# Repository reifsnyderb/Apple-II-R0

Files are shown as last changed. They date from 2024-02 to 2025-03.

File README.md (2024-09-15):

# APPLE II R0 Reproduction #

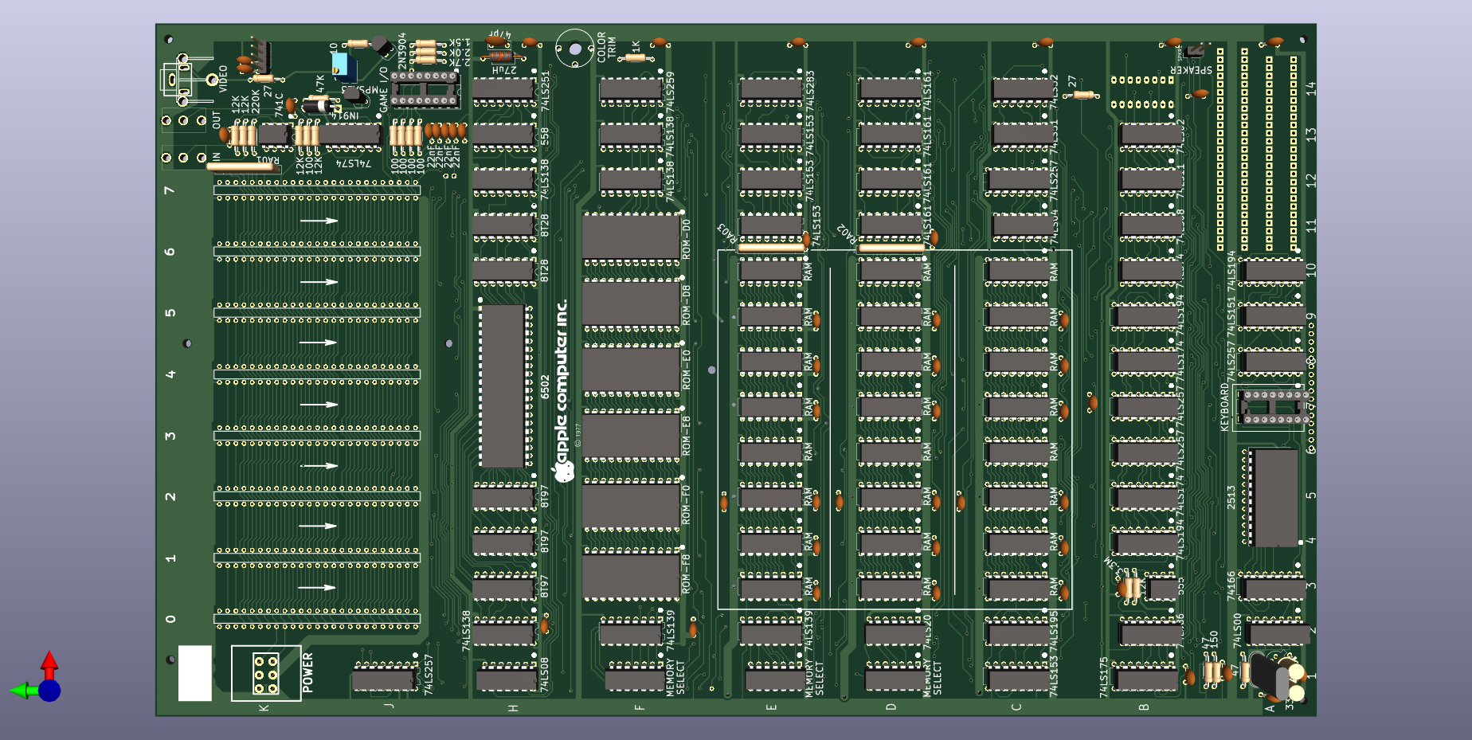
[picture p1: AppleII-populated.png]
Render of reproduction board


## Goal
The primary goal is to have an accurate KiCAD schematic of the 
Apple II Revision 0 System Board. This is supplemented with a
complete reproduction PCB that can be fabricated.

## Apple II R0 Notes

This schematic was taken from the [BitPreserve project](https://github.com/baldengineer/bit-preserve) and compared to the Apple II Gerbers by Mike Willegal (http://www.willegal.net/appleii/appleii-first_page.htm).
When necessary, The Apple II Circuit Description by Winston D. Gayler was consulted.

The PCB layout is a reworking of the Gerbers by Mike Willegal in 
KiCad. Where components are unobtainable from regular suppliers,
substitutes have been used with part number references.

## Current Status

1) Some errors have been found and corrected.
2) Minor work needs to be done to clean-up the schematic.
3) Minor cleanup is needed on the PCB.

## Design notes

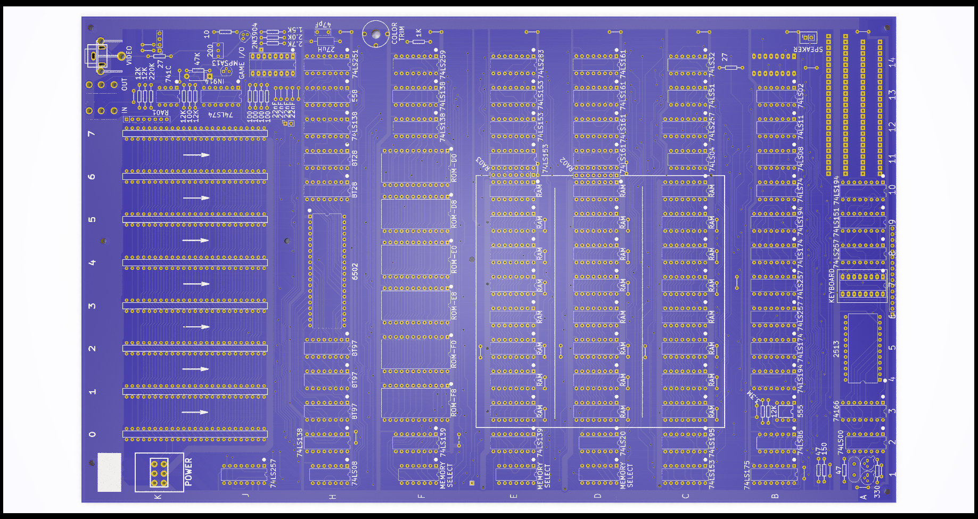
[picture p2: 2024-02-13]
AppleII.png

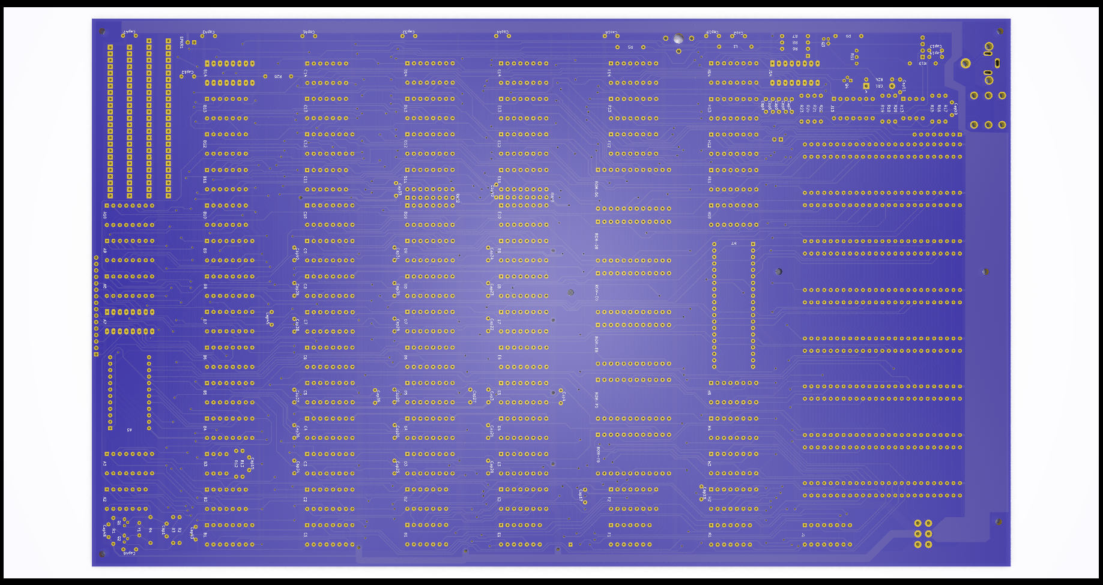
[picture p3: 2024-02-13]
AppleII-reverse.png

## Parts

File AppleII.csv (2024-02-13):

Source: | C:\Users\jimbr\Documents\KiCad\7.0\projects\Apple-II-R0\AppleII.kicad_sch
Date: | 02/02/2024 09:19:51
Tool: | Eeschema 7.0.10
Generator: | C:\Program Files\KiCad\7.0\bin\scripting\plugins/bom_csv_grouped_by_value.py
Component Count: | 196
Collated Components:
Item | Qty | Reference(s) | Value | LibPart | Footprint | Datasheet | DNP | Alt | Category | DK_Datasheet_Link | DK_Detail_Page | Description | Digi-Key_PN | DigiKey | Family | MPN | Manufacturer | Sim.Device | Sim.Pins | Status
1 | 1 | A2 | 74LS00 | 74xx:74LS00 | Package_DIP:DIP-14_W7.62mm | http://www.ti.com/lit/gpn/sn74ls00
2 | 1 | A3 | 74LS166 | 74xx:74LS166 | Package_DIP:DIP-16_W7.62mm | http://www.ti.com/lit/gpn/sn74LS166
3 | 1 | A5 | 2513 Char ROM | AppleII+:2513 | Package_DIP:DIP-24_W15.24mm
4 | 1 | A7 | Keyboard_Connector | AppleII+:AppleII+_Keyboard_Connector | Package_DIP:DIP-16_W7.62mm_Socket_LongPads
5 | 5 | A8, B6, B7, C12, J1 | 74LS257 | 74xx:74LS257 | Package_DIP:DIP-16_W7.62mm | http://www.ti.com/lit/gpn/sn74LS257
6 | 1 | A9 | 74LS151 | AppleII+:74LS151 | Package_DIP:DIP-16_W7.62mm | http://www.ti.com/lit/gpn/sn74LS151
7 | 3 | A10, B4, B9 | 74LS194 | 74xx:74LS194 | Package_DIP:DIP-16_W7.62mm | http://www.ti.com/lit/gpn/sn74LS194
8 | 1 | B1 | 74LS175 | AppleII+:74LS175 | Package_DIP:DIP-16_W7.62mm | http://www.ti.com/lit/gpn/sn74LS175
9 | 1 | B2 | 74LS86 | 74xx:74LS86 | Package_DIP:DIP-14_W7.62mm | 74xx/74ls86.pdf
10 | 1 | B3 | 555 | AppleII+:555_alt1 | Package_DIP:DIP-8_W7.62mm | http://www.ti.com/general/docs/suppproductinfo.tsp?distId=10 |  |  | Integrated Circuits (ICs) | http://www.ti.com/general/docs/suppproductinfo.tsp?distId=10 | /product-detail/en/texas-instruments/NE555P/296-1411-5-ND/277057 | IC OSC SINGLE TIMER 100KHZ 8-DIP | 296-1411-5-ND |  | Clock/Timing - Programmable Timers and Oscillators | NE555P | Texas Instruments |  |  | Active
11 | 2 | B5, B8 | 74LS174 | 74xx:74LS174 | Package_DIP:DIP-16_W7.62mm | http://www.ti.com/lit/gpn/sn74LS174
12 | 2 | B10, J13 | 74LS74 | 74xx:74LS74 | Package_DIP:DIP-14_W7.62mm | 74xx/74hc_hct74.pdf
13 | 2 | B11, H1 | 74LS08 | 74xx:74LS08 | Package_DIP:DIP-14_W7.62mm | http://www.ti.com/lit/gpn/sn74LS08
14 | 1 | B12 | 74LS11 | 74xx:74LS11 | Package_DIP:DIP-14_W7.62mm | http://www.ti.com/lit/gpn/sn74LS11
15 | 1 | B13 | 74LS02 | 74xx:74LS02 | Package_DIP:DIP-14_W7.62mm | http://www.ti.com/lit/gpn/sn74ls02
16 | 4 | C1, E11, E12, E13 | 74LS153 | 74xx:74LS153 | Package_DIP:DIP-16_W7.62mm | http://www.ti.com/lit/gpn/sn74LS153
17 | 1 | C2 | 74LS195 | 74xx:74LS195 | Package_DIP:DIP-16_W7.62mm | http://www.ti.com/lit/gpn/sn74LS195
18 | 24 | C3, C4, C5, C6, C7, C8, C9, C10, D3, D4, D5, D6, D7, D8, D9, D10, E3, E4, E5, E6, E7, E8, E9, E10 | 4116 | AppleII+:4116 | Package_DIP:DIP-16_W7.62mm
19 | 1 | C11 | 74LS04 | 74xx:74LS04 | Package_DIP:DIP-14_W7.62mm | http://www.ti.com/lit/gpn/sn74LS04
20 | 1 | C13 | 74LS51 | 74xx:74LS51 | Package_DIP:DIP-14_W7.62mm | http://www.ti.com/lit/ds/symlink/sn74ls51.pdf
21 | 1 | C14 | 74LS32 | 74xx:74LS32 | Package_DIP:DIP-14_W7.62mm | http://www.ti.com/lit/gpn/sn74LS32
22 | 37 | Cap1, Cap3, Cap4, Cap16, Cap17, Cap18, Cap19, Cap20, Cap21, Cap22, Cap23, Cap24, Cap25, Cap26, Cap27, Cap28, Cap29, Cap30, Cap31, Cap32, Cap33, Cap34, Cap35, Cap36, Cap37, Cap38, Cap39, Cap40, Cap41, Cap42, Cap43, Cap44, Cap45, Cap46, Cap47, Cap48, Cap49 | 0.1uF | Device:C_Small | Apple-II:C_Disc_D5.0mm_W2.5mm_P5.00mm | ~
23 | 1 | Cap2 | 47pf | Device:C_Small | Capacitor_THT:C_Disc_D7.0mm_W2.5mm_P5.00mm | ~
24 | 4 | Cap5, Cap6, Cap7, Cap8 | .022uF | Device:C_Small | Apple-II:C_Disc_D5.0mm_W2.5mm_P5.00mm | ~
25 | 4 | Cap9, Cap10, Cap11, Cap12 | .1uF | Device:C_Small | Apple-II:C_Disc_D5.0mm_W2.5mm_P5.00mm | ~
26 | 3 | Cap13, Cap14, Cap15 | 0.1uf | Device:C_Small | Apple-II:C_Disc_D5.0mm_W2.5mm_P5.00mm | ~
27 | 1 | CP0 | Power Connector | Connector_Generic:Conn_02x03_Odd_Even | Apple-II:POWER | https://www.te.com/commerce/DocumentDelivery/DDEController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 |  |  |  |  |  |  |  | A14226-ND
28 | 1 | CR1 | 1N914 | Device:D | Diode_THT:D_DO-15_P10.16mm_Horizontal | ~ |  |  |  |  |  |  |  |  |  |  |  | D | 1=K 2=A
29 | 1 | CT3 | 5-50pF | Device:C_Trim_Differential | Apple-II:COLOUR_TRIM | https://www.vishay.com/docs/28528/bfc2808-10mm.pdf |  |  |  |  |  |  |  | BFC280831659-ND
30 | 3 | D1, E1, F1 | Memory Type Sel | AppleII+:AppII_MemorySelectBlock | Package_DIP:DIP-14_W7.62mm
31 | 1 | D2 | 74LS20 | 74xx:74LS20 | Package_DIP:DIP-14_W7.62mm | http://www.ti.com/lit/gpn/sn74LS20
32 | 4 | D11, D12, D13, D14 | 74LS161 | AppleII+:74LS161 | Package_DIP:DIP-16_W7.62mm | http://www.ti.com/lit/gpn/sn74LS161
33 | 2 | E2, F2 | 74LS139 | 74xx:74LS139 | Package_DIP:DIP-16_W7.62mm | http://www.ti.com/lit/ds/symlink/sn74ls139a.pdf
34 | 1 | E14 | 74LS283 | 74xx:74LS283 | Package_DIP:DIP-16_W7.62mm | http://www.ti.com/lit/gpn/sn74LS283
35 | 4 | F12, F13, H2, H12 | 74LS138 | 74xx:74LS138 | Package_DIP:DIP-16_W7.62mm | http://www.ti.com/lit/gpn/sn74LS138
36 | 1 | F14 | 74LS259 | 74xx:74LS259 | Package_DIP:DIP-16_W7.62mm | http://www.ti.com/lit/gpn/sn74LS259
37 | 2 | H3, H4 | 8T97 | AppleII+:8T97 | Package_DIP:DIP-16_W7.62mm
38 | 1 | H5 | 8T97 | AppleII-rescue:8T97-AppleII | Package_DIP:DIP-16_W7.62mm
39 | 1 | H7 | 6502 | AppleII-rescue:MOS6502-AppleII | Package_DIP:DIP-40_W15.24mm
40 | 2 | H10, H11 | 8T28 | AppleII-rescue:8T28-AppleII | Package_DIP:DIP-16_W7.62mm
41 | 1 | H13 | NE558 | AppleII+:NE558 | Package_DIP:DIP-16_W7.62mm
42 | 1 | H14 | 74LS251 | 74xx:74LS251 | Package_DIP:DIP-16_W7.62mm | http://www.ti.com/lit/gpn/sn74LS251
43 | 1 | J0 | Cassette Data In | Connector_Audio:AudioJack2_Ground | Apple-II:AUDIO_mono | https://www.cuidevices.com/product/resource/mj-3502n.pdf |  |  |  |  |  |  |  | CP-3502N-ND
44 | 1 | J2 | Cassette Data Out | Connector_Audio:AudioJack2_Ground | Apple-II:AUDIO_mono | https://www.cuidevices.com/product/resource/mj-3502n.pdf |  |  |  |  |  |  |  | CP-3502N-ND
45 | 1 | J3 | Conn_01x16 | Connector_Generic:Conn_01x16 | Connector_PinHeader_2.54mm:PinHeader_1x16_P2.54mm_Vertical | ~
46 | 1 | J14 | GAME_IO_Conn | AppleII+:GAME_IO_Conn | Package_DIP:DIP-16_W7.62mm_Socket_LongPads
47 | 1 | J18 | Aux Video | Connector_Generic:Conn_01x04 | Connector_PinHeader_2.54mm:PinHeader_1x04_P2.54mm_Vertical | ~
48 | 1 | JP-User1 | Jumper | Jumper:Jumper_2_Open | Connector_PinSocket_2.54mm:PinSocket_1x02_P2.54mm_Vertical | ~ | DNP
49 | 1 | K13 | MA741 | Amplifier_Operational:LM741 | Package_DIP:DIP-8_W7.62mm | http://www.ti.com/lit/ds/symlink/lm741.pdf
50 | 1 | K14 | RCA Connector | Apple-II:Video | Apple-II:VIDEO | https://www.switchcraft.com/assets/1/24/pjran1x1u__x_series_cd.pdf?4664 |  |  |  |  |  |  |  | PJRAN1X1U03X-ND
51 | 1 | L1 | 27uH | Device:L | Inductor_THT:L_Axial_L7.0mm_D3.3mm_P12.70mm_Horizontal_Fastron_MICC | ~
52 | 7 | MH1, MH2, MH3, MH4, MH5, MH6, MH7 | MountingHole | Mechanical:MountingHole | MountingHole:MountingHole_2.5mm | ~
53 | 2 | Q1, Q2 | 2N4258 | Device:Q_PNP_EBC | Package_TO_SOT_THT:TO-18-3 | ~ |  | 2N4208 |  |  |  |  |  | 2N4208-ND
54 | 1 | Q3 | 2N3904 | AppleII-rescue:2N3904-dk_Transistors-Bipolar-BJT-Single | Package_TO_SOT_THT:TO-92 | https://my.centralsemi.com/get_document.php?cmp=1&mergetype=pd&mergepath=pd&pdf_id=LSSGP072.PDF |  |  | Discrete Semiconductor Products | https://my.centralsemi.com/get_document.php?cmp=1&mergetype=pd&mergepath=pd&pdf_id=LSSGP072.PDF | /product-detail/en/central-semiconductor-corp/2N3904/2N3904CS-ND/4806876 | TRANS NPN 40V TO-92 | 2N3904CS-ND |  | Transistors - Bipolar (BJT) - Single | 2N3904 | Central Semiconductor Corp |  |  | Active
55 | 1 | Q4 | MPSA13 | Device:Q_NPN_Darlington_EBC | Package_TO_SOT_THT:TO-92 | ~ |  | KSP13 |  |  |  |  |  | KSP13BU-ND
56 | 1 | R1 | 330R | Device:R | Apple-II:R_Axial_DIN0207_L6.3mm_D2.5mm_P10.16mm_Horizontal | ~
57 | 2 | R2, R4 | 47R | Device:R | Apple-II:R_Axial_DIN0207_L6.3mm_D2.5mm_P10.16mm_Horizontal | ~
58 | 1 | R3 | 150R | Device:R | Apple-II:R_Axial_DIN0207_L6.3mm_D2.5mm_P10.16mm_Horizontal | ~
59 | 1 | R5 | 1K | Device:R | Apple-II:R_Axial_DIN0207_L6.3mm_D2.5mm_P10.16mm_Horizontal | ~
60 | 1 | R6 | 2K7 | Device:R | Apple-II:R_Axial_DIN0207_L6.3mm_D2.5mm_P10.16mm_Horizontal | ~
61 | 1 | R7 | 1K5 | Device:R | Apple-II:R_Axial_DIN0207_L6.3mm_D2.5mm_P10.16mm_Horizontal | ~
62 | 1 | R8 | 2K | Device:R | Apple-II:R_Axial_DIN0207_L6.3mm_D2.5mm_P10.16mm_Horizontal | ~
63 | 1 | R9 | 10R | Device:R | Apple-II:R_Axial_DIN0207_L6.3mm_D2.5mm_P10.16mm_Horizontal | ~
64 | 1 | R10 | 27R | Device:R | Apple-II:R_Axial_DIN0207_L6.3mm_D2.5mm_P10.16mm_Horizontal | ~
65 | 1 | R11 | 200R | AppleII-rescue:R_POT_TRIM_US-Device | Potentiometer_THT:Potentiometer_Bourns_3266Y_Vertical
66 | 1 | R12 | 12K | Device:R | Apple-II:R_Axial_DIN0207_L6.3mm_D2.5mm_P10.16mm_Horizontal | ~
67 | 1 | R13 | 3M3 | Device:R | Apple-II:R_Axial_DIN0207_L6.3mm_D2.5mm_P10.16mm_Horizontal | ~
68 | 1 | R15 | 220k | Device:R_Small | Apple-II:R_Axial_DIN0207_L6.3mm_D2.5mm_P10.16mm_Horizontal | ~
69 | 4 | R16, R17, R19, R29 | 12K | Device:R_Small | Apple-II:R_Axial_DIN0207_L6.3mm_D2.5mm_P10.16mm_Horizontal | ~
70 | 5 | R18, R20, R21, R22, R23 | 100R | Device:R_Small | Apple-II:R_Axial_DIN0207_L6.3mm_D2.5mm_P10.16mm_Horizontal | ~
71 | 1 | R24 | 47K | Device:R_Small | Apple-II:R_Axial_DIN0207_L6.3mm_D2.5mm_P10.16mm_Horizontal | ~
72 | 1 | R25 | 27R | Device:R_Small | Apple-II:R_Axial_DIN0207_L6.3mm_D2.5mm_P10.16mm_Horizontal | ~
73 | 1 | RA01 | 1k | Device:R_Network07_US | Resistor_THT:R_Array_SIP8 | http://www.vishay.com/docs/31509/csc.pdf
74 | 2 | RA02, RA03 | 1K | Device:R_Network07_US | Resistor_THT:R_Array_SIP8 | http://www.vishay.com/docs/31509/csc.pdf
75 | 6 | ROM-D0, ROM-D8, ROM-E0, ROM-E8, ROM-F0, ROM-F8 | ROM_Chip | AppleII+:ROM_Chip | Package_DIP:DIP-24_W15.24mm
76 | 8 | SLOT0, SLOT1, SLOT2, SLOT3, SLOT4, SLOT5, SLOT6, SLOT7 | 50 pin slot | Connector_Generic:Conn_02x25_Counter_Clockwise | Apple-II:Standard_Edge_Connector | ~ |  |  |  |  |  |  |  | A31718-ND
77 | 1 | SPKR1 | Speaker Connector | AppleII-rescue:22-23-2021-dk_Rectangular-Connectors-Headers-Male-Pins | Connector_PinSocket_2.54mm:PinSocket_1x02_P2.54mm_Vertical | https://media.digikey.com/pdf/Data%20Sheets/Molex%20PDFs/A-6373-N_Series_Dwg_2010-12-03.pdf |  |  | Connectors, Interconnects | https://media.digikey.com/pdf/Data%20Sheets/Molex%20PDFs/A-6373-N_Series_Dwg_2010-12-03.pdf | /product-detail/en/molex/22-23-2021/WM4200-ND/26667 | CONN HEADER VERT 2POS 2.54MM | WM4200-ND |  | Rectangular Connectors - Headers, Male Pins | 22-23-2021 | Molex |  |  | Active
78 | 1 | Y1 | XT0001 | Device:Crystal | Crystal:Crystal_HC18-U_Vertical | ~

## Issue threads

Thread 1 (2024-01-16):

PC Board file is needed

reifsnyderb, 2024-01-16:
PC Board file is missing as it was made from imported gerber files from M. Willegal's Apple II Revision 0 board.  KiCad, unfortunately, imported them with the wrong track thickness.  Extensive work will be required to re-set the track thicknesses properly.

jimbro1000, 2024-01-27:
I've started routing tracks by hand based on those gerbers and found some issues with the schematics as a result - will post them as separate issues

reifsnyderb, 2024-02-13:
PCB board is now available.  Closing issue.

Closed 2024-02-13.

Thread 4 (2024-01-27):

Incorrect use of labels

jimbro1000, 2024-01-27:
On the Connectors sheet (page 7) you've used local labels to match against global labels but on the CPU sheet (page 2) you've matched local labels against hierarchical labels. The result is that on a PCB these do not actually connect.

This impacts NMI, IRQ, RDY and RESET

reifsnyderb, 2024-01-27:
NMI, IRQ, and RDY are fixed.  RESET still appears to have some issue.

jimbro1000, 2024-01-29:
This happens again (sort of) with the ROM_Select_Dn lines. You've used local labels for them but they are distributed over page 9 and 5 so the connection is not made on the PCB

reifsnyderb, 2024-01-30:
ROM Select Line issue fixed.

reifsnyderb, 2024-01-30:
RESET fixed.

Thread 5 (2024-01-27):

Slot 0-7 connection pin 19

jimbro1000, 2024-01-27:
Based on the imported gerbers, pin 19 of the 8 slots are cross-wired together but are otherwise unused

reifsnyderb, 2024-01-28:
Fixed connections with pins 19 and pins 35.

Closed 2024-01-28.

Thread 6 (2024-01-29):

Label mismatch on IO-Select-N

jimbro1000, 2024-01-29:
The global labels for IO Select are mismatched
On page 7 they are fully uppercase (eg IO-SELECT-6) but on 9 they are mixed case (eg IO-Select-6)
The labels are case-sensitive and do not match up

reifsnyderb, 2024-01-30:
Fixed.

Closed 2024-01-30.

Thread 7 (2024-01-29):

Unit H1E (VCC and GND) is missing

jimbro1000, 2024-01-29:
The final unit for H1 is missing from the schematic

reifsnyderb, 2024-01-30:
Added.

Closed 2024-01-30.

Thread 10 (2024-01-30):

More SOFT5 connections

jimbro1000, 2024-01-30:
B10 pin 10 is shown as unconnected but is wired to SOFT5 on the PCB (note pin 12 is also unconnected correctly but not tagged as such)

reifsnyderb, 2024-01-30:
Fixed.

Closed 2024-01-30.

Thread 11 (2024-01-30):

D2 unit C missing

jimbro1000, 2024-01-30:
D2 unit C is missing from the schematic

reifsnyderb, 2024-01-30:
Fixed.

Closed 2024-01-30.

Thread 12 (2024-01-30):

Crosswired connection on D12

jimbro1000, 2024-01-30:
!PE is cross wired with D0-D3, CET and CEP. On the PCB !PE is not connected. D11 doesn't have the cross wired connection

reifsnyderb, 2024-01-31:
Fixed.

Closed 2024-01-31.

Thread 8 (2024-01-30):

H14 - Pin 6 incorrect

jimbro1000, 2024-01-30:
This is tied to ground on the PCB

reifsnyderb, 2024-01-30:
This issue is rather somewhat conflicting.  The PCB clearly ties this to ground.  However, H14 pin 6 of the 74LS251 is an output and would be shorted out to ground when it is high.  Maybe this is a PCB error?

reifsnyderb, 2024-01-30:
A note has been put on the schematic as a temporary measure.

reifsnyderb, 2024-02-01:
Attempting to contact Mike Willegal to determine if this was an error on the Apple II Rev 0 boards.

reifsnyderb, 2024-02-02:
This has been confirmed, by Mike Willegal, to be a mistake and will be corrected on the PCB.

reifsnyderb, 2024-02-02:
PCB has been fixed.

Closed 2024-02-02.

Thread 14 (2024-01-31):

!MR on D11 and D12

jimbro1000, 2024-01-31:
PCB shows !MR for D11 and D12 connected to SOFT5 - schematic shows the two ICs connected but not to anything else which is unlikely to be correct

reifsnyderb, 2024-01-31:
Fixed

Closed 2024-01-31.

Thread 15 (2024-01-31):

C13 unit C and C14 unit E missing

jimbro1000, 2024-01-31:
C13C and C14E are missing from the schematic

jimbro1000, 2024-01-31:
Need to add C11G to the list

jimbro1000, 2024-01-31:
And B2E

jimbro1000, 2024-01-31:
And B13E

Closed 2024-01-31.

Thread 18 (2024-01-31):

A2 Unit E missing

jimbro1000, 2024-01-31:
Unit E of IC A2 is missing from the schematic

reifsnyderb, 2024-01-31:
Fixed

Closed 2024-01-31.

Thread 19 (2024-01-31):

A8 wiring mismatch

jimbro1000, 2024-01-31:
PCB shows A8 15 (!OE), 13 8 and 6 are all wired together (GND) not to another signal (labelled A8-6) as indicated on the schematic

reifsnyderb, 2024-01-31:
Fixed.

Closed 2024-01-31.

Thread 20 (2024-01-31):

Not an issue - PCB routing completed

jimbro1000, 2024-01-31:
I think I've finished routing the PCB with all of the updates and changes I've raised but this is now out of sync with your schematics so I'm not going to just raise a pull request

The cosmetics of the board still need work to get all of the labelling correct, likewise placing of mounting holes

See my fork of the repo for renders and pcb files for comparison

jimbro1000, 2024-01-31:
OK - not quite finished, there is an issue with the SOFT5 net. There are two separate nets labelled SOFT5 generated from A2 (pin 8 and pin 11). Other than the gates driving them being on the same chip, they are not otherwise connected. Given that SOFT5 is just always high (inverted GND) I suggest that the net names are changed... the only impact is fixing DRC errors on the PCB, the schematic is otherwise correct

reifsnyderb, 2024-01-31:
Make them SOFT5a and SOFT5b?  Tracking down this issue could take a while.

jimbro1000, 2024-01-31:
That's what I was thinking - it is really quick to isolate the nets in the PCB editor so I should be able to give you a list of the two sides

jimbro1000, 2024-01-31:
I've found modern substitutes for everything except the character rom but it should be simple enough to convert a 27C16 to suit

reifsnyderb, 2024-01-31:
Thank you for all your work on this!  I just downloaded and was looking at your PCB.  It's looking good!

When ready (no rush), post a list and I'll isolate the two SOFT5 nets.

reifsnyderb, 2024-01-31:
I just found and opened up the discussion section.

Are these modern substitutes still being made?

jimbro1000, 2024-01-31:
Other than the roms I think everything is current on digikey and I've tagged components with the digikey part numbers as I've identified them. The roms can be directly substituted with 27c16 EPROMs but the character Rom is problematic by comparison

Closed 2024-02-02.

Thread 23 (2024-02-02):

Loose ends

jimbro1000, 2024-02-02:
There are two incomplete tracks in the original gerbers
Net-(E2A-O0) heads west near the edge of the board (just above E1) but I can't identify anything it intended to connect to

The Color_Burst trace heads west from R6 (connects R6,R7 and R8). It looks as though there was meant to be a fourth resistor in the bank but was not implemented. There is nowhere for the pads to fit as the traces from J14 occupy that space

Before I simply delete the loose ends can you verify I haven't missed anything against the old boards you have?
This is an otherwise cosmetic problem

reifsnyderb, 2024-02-02:
The Color_Burst trace goes to a via that appears it could be used as a test point. The metal around the via is masked off.  If the via size is unclear, let me know and I'll take some accurate measurements.  I also checked Mike Willegal's site and he has a close-up of this area and this trace (and via) is on the original Apple II R 0.

The E2A-O0 appears on the board as well.  It terminates as a VIA.  I found a close-up here:  https://medium.com/@piedad/prime-properties-for-sale-e398359440a  So, it appears it should be left in place.

Closed 2024-02-02.

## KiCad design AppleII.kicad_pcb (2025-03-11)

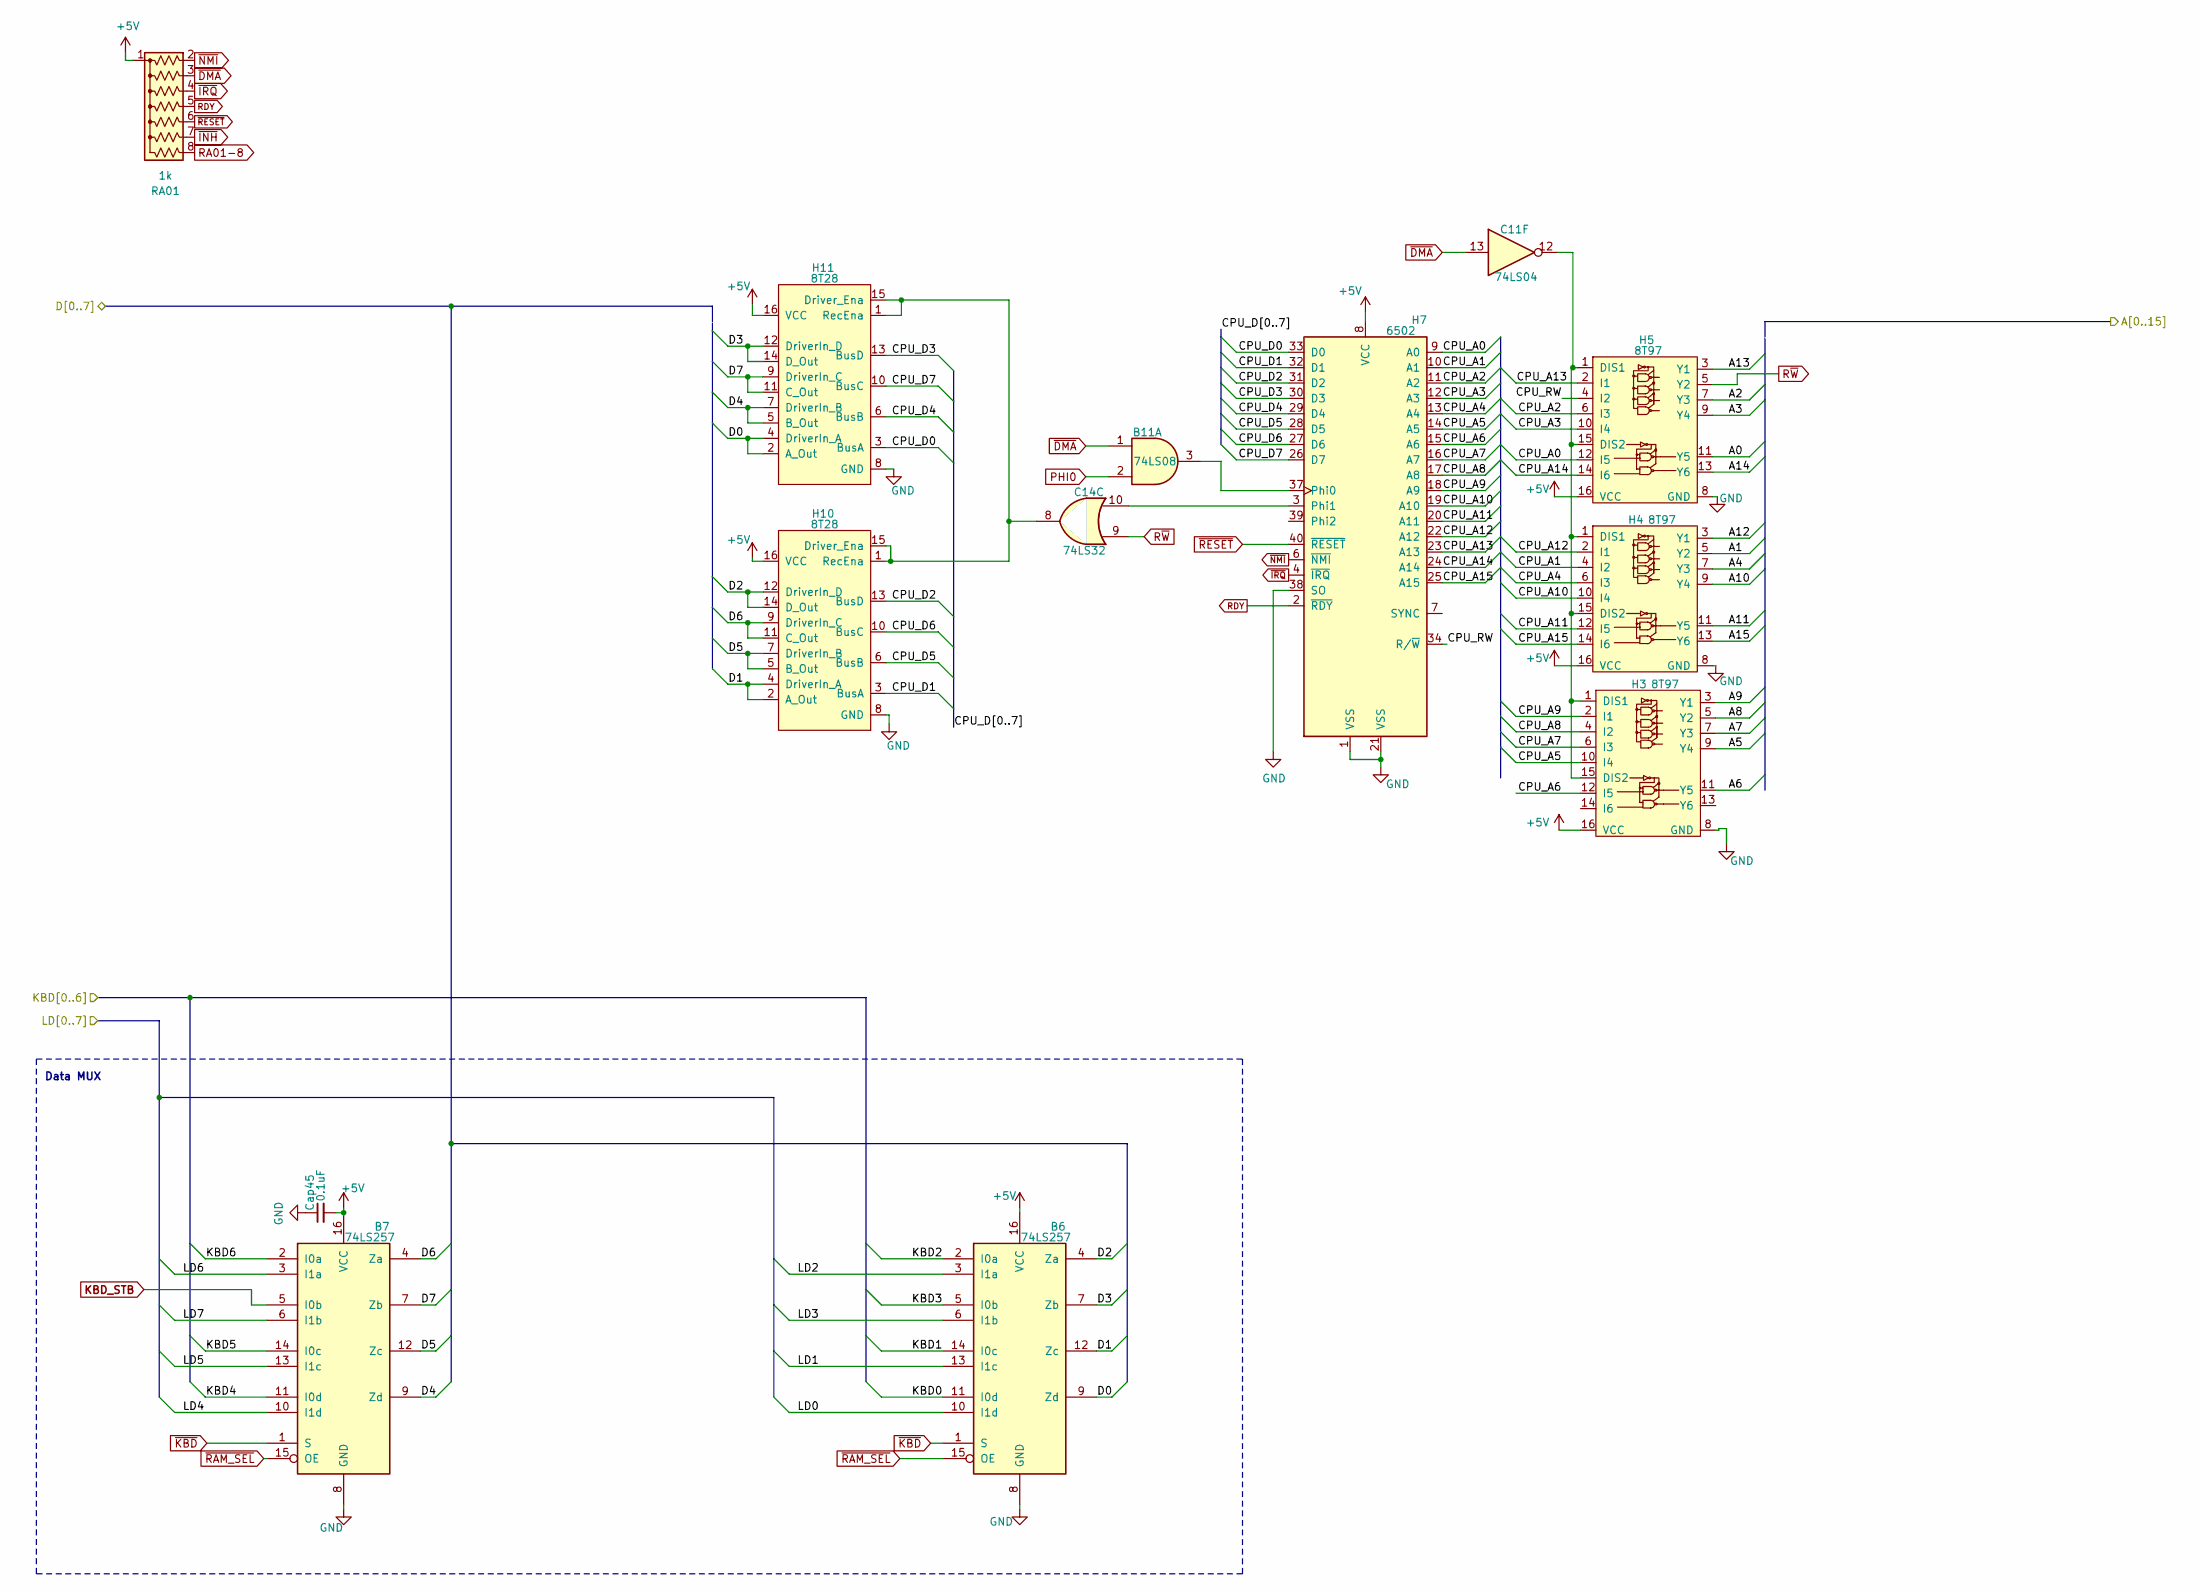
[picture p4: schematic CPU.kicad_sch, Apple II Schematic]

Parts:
B6, B7: 74LS257; DIP-16_W7.62mm
B11: 74LS08; DIP-14_W7.62mm
C11: 74LS04; DIP-14_W7.62mm
C14: 74LS32; DIP-14_W7.62mm
Cap45: 0.1uF; C_Disc_D5.0mm_W2.5mm_P5.00mm
H3, H4, H5: 8T97; DIP-16_W7.62mm
H7: 6502; DIP-40_W15.24mm
H10, H11: 8T28; DIP-16_W7.62mm
RA01: 1k; R_Array_SIP8

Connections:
+5V: B6.16 (VCC), B7.16 (VCC), Cap45.2, H3.16 (VCC), H4.16 (VCC), H5.16 (VCC), H7.8 (VCC), H10.16 (VCC), H11.16 (VCC), RA01.1 (common); also elsewhere on the board
/Address Decoder and Onboard IO/KBD0: B6.11 (I0d); also elsewhere on the board
/Address Decoder and Onboard IO/KBD1: B6.14 (I0c); also elsewhere on the board
/Address Decoder and Onboard IO/KBD2: B6.2 (I0a); also elsewhere on the board
/Address Decoder and Onboard IO/KBD3: B6.5 (I0b); also elsewhere on the board
/Address Decoder and Onboard IO/KBD4: B7.11 (I0d); also elsewhere on the board
/Address Decoder and Onboard IO/KBD5: B7.14 (I0c); also elsewhere on the board
/Address Decoder and Onboard IO/KBD6: B7.2 (I0a); also elsewhere on the board
/CPU Tranceiver Driver and Data MUX/CPU_A0: H5.12 (I5), H7.9 (A0)
/CPU Tranceiver Driver and Data MUX/CPU_A1: H4.4 (I2), H7.10 (A1)
/CPU Tranceiver Driver and Data MUX/CPU_A2: H5.6 (I3), H7.11 (A2)
/CPU Tranceiver Driver and Data MUX/CPU_A3: H5.10 (I4), H7.12 (A3)
/CPU Tranceiver Driver and Data MUX/CPU_A4: H4.6 (I3), H7.13 (A4)
/CPU Tranceiver Driver and Data MUX/CPU_A5: H3.10 (I4), H7.14 (A5)
/CPU Tranceiver Driver and Data MUX/CPU_A6: H3.12 (I5), H7.15 (A6)
/CPU Tranceiver Driver and Data MUX/CPU_A7: H3.6 (I3), H7.16 (A7)
/CPU Tranceiver Driver and Data MUX/CPU_A8: H3.4 (I2), H7.17 (A8)
/CPU Tranceiver Driver and Data MUX/CPU_A9: H3.2 (I1), H7.18 (A9)
/CPU Tranceiver Driver and Data MUX/CPU_A10: H4.10 (I4), H7.19 (A10)
/CPU Tranceiver Driver and Data MUX/CPU_A11: H4.12 (I5), H7.20 (A11)
/CPU Tranceiver Driver and Data MUX/CPU_A12: H4.2 (I1), H7.22 (A12)
/CPU Tranceiver Driver and Data MUX/CPU_A13: H5.2 (I1), H7.23 (A13)
/CPU Tranceiver Driver and Data MUX/CPU_A14: H5.14 (I6), H7.24 (A14)
/CPU Tranceiver Driver and Data MUX/CPU_A15: H4.14 (I6), H7.25 (A15)
/CPU Tranceiver Driver and Data MUX/CPU_D0: H7.33 (D0), H11.3 (BusA)
/CPU Tranceiver Driver and Data MUX/CPU_D1: H7.32 (D1), H10.3 (BusA)
/CPU Tranceiver Driver and Data MUX/CPU_D2: H7.31 (D2), H10.13 (BusD)
/CPU Tranceiver Driver and Data MUX/CPU_D3: H7.30 (D3), H11.13 (BusD)
/CPU Tranceiver Driver and Data MUX/CPU_D4: H7.29 (D4), H11.6 (BusB)
/CPU Tranceiver Driver and Data MUX/CPU_D5: H7.28 (D5), H10.6 (BusB)
/CPU Tranceiver Driver and Data MUX/CPU_D6: H7.27 (D6), H10.10 (BusC)
/CPU Tranceiver Driver and Data MUX/CPU_D7: H7.26 (D7), H11.10 (BusC)
/CPU Tranceiver Driver and Data MUX/CPU_RW: H5.4 (I2), H7.34 (R/~W)
/CPU Tranceiver Driver and Data MUX/LD0: B6.10 (I1d); also elsewhere on the board
/CPU Tranceiver Driver and Data MUX/LD1: B6.13 (I1c); also elsewhere on the board
/CPU Tranceiver Driver and Data MUX/LD2: B6.3 (I1a); also elsewhere on the board
/CPU Tranceiver Driver and Data MUX/LD3: B6.6 (I1b); also elsewhere on the board
/CPU Tranceiver Driver and Data MUX/LD4: B7.10 (I1d); also elsewhere on the board
/CPU Tranceiver Driver and Data MUX/LD5: B7.13 (I1c); also elsewhere on the board
/CPU Tranceiver Driver and Data MUX/LD6: B7.3 (I1a); also elsewhere on the board
/CPU Tranceiver Driver and Data MUX/LD7: B7.6 (I1b); also elsewhere on the board
A0: H5.11 (Y5); also elsewhere on the board
A1: H4.5 (Y2); also elsewhere on the board
A2: H5.7 (Y3); also elsewhere on the board
A3: H5.9 (Y4); also elsewhere on the board
A4: H4.7 (Y3); also elsewhere on the board
A5: H3.9 (Y4); also elsewhere on the board
A6: H3.11 (Y5); also elsewhere on the board
A7: H3.7 (Y3); also elsewhere on the board
A8: H3.5 (Y2); also elsewhere on the board
A9: H3.3 (Y1); also elsewhere on the board
A10: H4.9 (Y4); also elsewhere on the board
A11: H4.11 (Y5); also elsewhere on the board
A12: H4.3 (Y1); also elsewhere on the board
A13: H5.3 (Y1); also elsewhere on the board
A14: H5.13 (Y6); also elsewhere on the board
A15: H4.13 (Y6); also elsewhere on the board
D0: B6.9 (Zd), H11.2 (A_Out), H11.4 (DriverIn_A); also elsewhere on the board
D1: B6.12 (Zc), H10.2 (A_Out), H10.4 (DriverIn_A); also elsewhere on the board
D2: B6.4 (Za), H10.12 (DriverIn_D), H10.14 (D_Out); also elsewhere on the board
D3: B6.7 (Zb), H11.12 (DriverIn_D), H11.14 (D_Out); also elsewhere on the board
D4: B7.9 (Zd), H11.5 (B_Out), H11.7 (DriverIn_B); also elsewhere on the board
D5: B7.12 (Zc), H10.5 (B_Out), H10.7 (DriverIn_B); also elsewhere on the board
D6: B7.4 (Za), H10.9 (DriverIn_C), H10.11 (C_Out); also elsewhere on the board
D7: B7.7 (Zb), H11.9 (DriverIn_C), H11.11 (C_Out); also elsewhere on the board
GND: B6.8 (GND), B7.8 (GND), Cap45.1, H3.8 (GND), H4.8 (GND), H5.8 (GND), H7.1 (VSS), H7.21 (VSS), H7.38 (SO), H10.8 (GND), H11.8 (GND); also elsewhere on the board
KBD_STB: B7.5 (I0b); also elsewhere on the board
unnamed: C11.12, H3.1 (DIS1), H3.15 (DIS2), H4.1 (DIS1), H4.15 (DIS2), H5.1 (DIS1), H5.15 (DIS2)
unnamed: B11.3, H7.37 (Phi0)
unnamed: C14.10, H7.3 (Phi1)
unnamed: C14.8, H10.1 (RecEna), H10.15 (Driver_Ena), H11.1 (RecEna), H11.15 (Driver_Ena)
PHI0: B11.2; also elsewhere on the board
RA01-8: RA01.8 (R7); also elsewhere on the board
RDY: H7.2 (~RDY), RA01.5 (R4); also elsewhere on the board
R~W: C14.9, H5.5 (Y2); also elsewhere on the board
~DMA: B11.1, C11.13, RA01.3 (R2); also elsewhere on the board
~INH: RA01.7 (R6); also elsewhere on the board
~IRQ: H7.4 (~IRQ), RA01.4 (R3); also elsewhere on the board
~KBD: B6.1 (S), B7.1 (S); also elsewhere on the board
~NMI: H7.6 (~NMI), RA01.2 (R1); also elsewhere on the board
~RAM_SEL: B6.15 (OE), B7.15 (OE); also elsewhere on the board
~RESET: H7.40 (~RESET), RA01.6 (R5); also elsewhere on the board

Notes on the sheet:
Data MUX

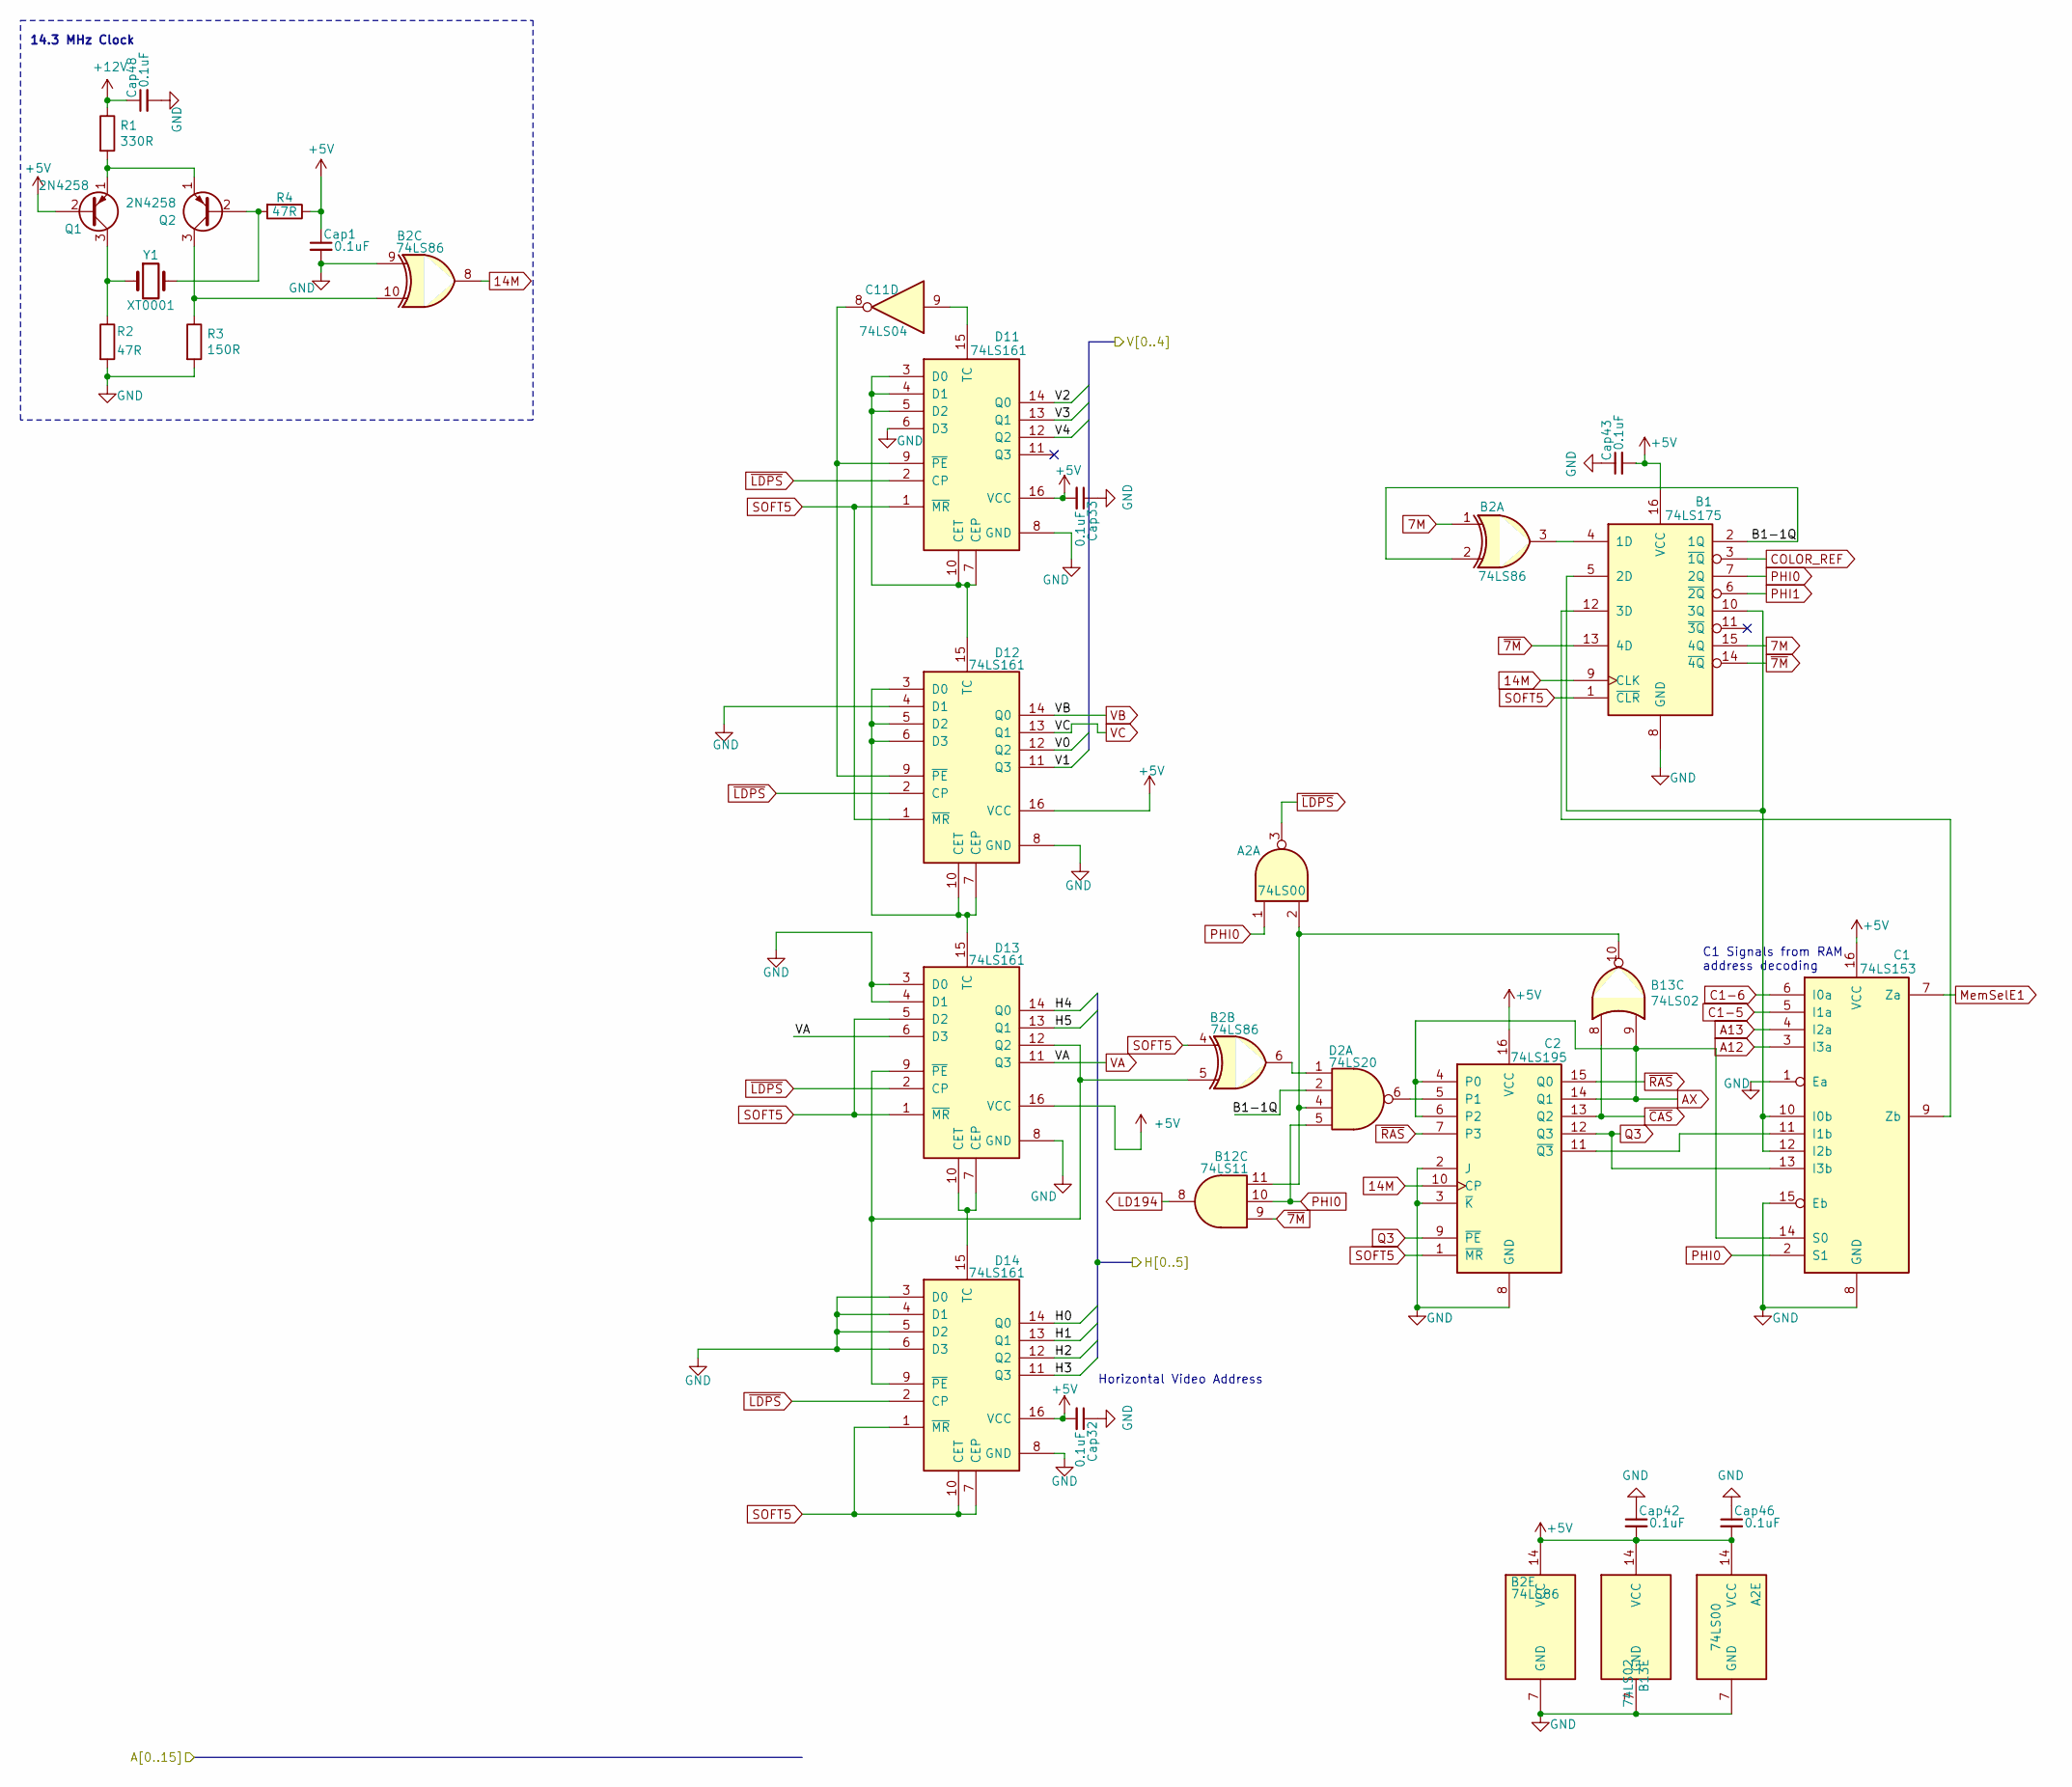
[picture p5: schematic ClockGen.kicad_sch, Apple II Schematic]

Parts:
A2: 74LS00; DIP-14_W7.62mm
B1: 74LS175; DIP-16_W7.62mm
B2: 74LS86; DIP-14_W7.62mm
B12: 74LS11; DIP-14_W7.62mm
B13: 74LS02; DIP-14_W7.62mm
C1: 74LS153; DIP-16_W7.62mm
C2: 74LS195; DIP-16_W7.62mm
C11: 74LS04; DIP-14_W7.62mm
Cap1, Cap32, Cap33, Cap42, Cap43, Cap46, Cap48: 0.1uF; C_Disc_D5.0mm_W2.5mm_P5.00mm
D2: 74LS20; DIP-14_W7.62mm
D11, D12, D13, D14: 74LS161; DIP-16_W7.62mm
Q1, Q2: 2N4258; TO-18-3; DigiKey 2N4208-ND
R1: 330R; R_Axial_DIN0207_L6.3mm_D2.5mm_P10.16mm_Horizontal
R2, R4: 47R; R_Axial_DIN0207_L6.3mm_D2.5mm_P10.16mm_Horizontal
R3: 150R; R_Axial_DIN0207_L6.3mm_D2.5mm_P10.16mm_Horizontal
Y1: XT0001; Crystal_HC18-U_Vertical

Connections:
7M: B1.15 (4Q), B2.1; also elsewhere on the board
14M: B1.9 (CLK), B2.8, C2.10 (CP); also elsewhere on the board
+5V: A2.14 (VCC), B1.16 (VCC), B2.14 (VCC), B13.14 (VCC), C1.16 (VCC), C2.16 (VCC), Cap1.1, Cap32.2, Cap33.2, Cap42.2, Cap43.2, Cap46.2, D11.16 (VCC), D12.16 (VCC), D13.16 (VCC), D14.16 (VCC), Q1.2 (B), R4.1; also elsewhere on the board
+12V: Cap48.1, R1.1; also elsewhere on the board
/Clock Generation/B1-1Q: B1.2 (1Q), B2.2, D2.2
/Clock Generation/H0: D14.14 (Q0); also elsewhere on the board
/Clock Generation/H1: D14.13 (Q1); also elsewhere on the board
/Clock Generation/H2: D14.12 (Q2); also elsewhere on the board
/Clock Generation/H3: D14.11 (Q3); also elsewhere on the board
/Clock Generation/H4: D13.14 (Q0); also elsewhere on the board
/Clock Generation/H5: D13.13 (Q1); also elsewhere on the board
/Clock Generation/V1: D12.11 (Q3); also elsewhere on the board
/Clock Generation/V2: D11.14 (Q0); also elsewhere on the board
/Clock Generation/V3: D11.13 (Q1); also elsewhere on the board
/Clock Generation/V4: D11.12 (Q2); also elsewhere on the board
A12: C1.3 (I3a); also elsewhere on the board
A13: C1.4 (I2a); also elsewhere on the board
AX: B13.9, C1.14 (S0), C2.4 (P0), C2.6 (P2), C2.14 (Q1); also elsewhere on the board
C1-5: C1.5 (I1a); also elsewhere on the board
C1-6: C1.6 (I0a); also elsewhere on the board
COLOR_REF: B1.3 (~1Q); also elsewhere on the board
GND: A2.7 (GND), B1.8 (GND), B2.7 (GND), B2.9, B13.7 (GND), C1.1 (Ea), C1.8 (GND), C1.15 (Eb), C2.2 (J), C2.3 (~K), C2.8 (GND), Cap1.2, Cap32.1, Cap33.1, Cap42.1, Cap43.1, Cap46.1, Cap48.2, D11.6 (D3), D11.8 (GND), D12.4 (D1), D12.8 (GND), D13.3 (D0), D13.4 (D1), D13.8 (GND), D14.3 (D0), D14.4 (D1), D14.5 (D2), D14.6 (D3), D14.8 (GND), R2.2, R3.2; also elsewhere on the board
LD194: B12.8; also elsewhere on the board
MemSelE1: C1.7 (Za); also elsewhere on the board
unnamed: A2.2, B12.11, B13.10, D2.4
unnamed: B1.4 (1D), B2.3
unnamed: B1.5 (2D), B1.10 (3Q), C1.10 (I0b), C1.12 (I2b)
unnamed: B1.12 (3D), C1.9 (Zb)
unnamed: B2.6, D2.1
unnamed: C1.11 (I1b), C2.11 (~Q3)
unnamed: C2.5 (P1), D2.6
unnamed: D11.3 (D0), D11.4 (D1), D11.5 (D2), D11.7 (CEP), D11.10 (CET), D12.15 (TC)
unnamed: C11.9, D11.15 (TC)
unnamed: C11.8, D11.9 (~PE), D12.9 (~PE)
unnamed: D12.3 (D0), D12.5 (D2), D12.6 (D3), D12.7 (CEP), D12.10 (CET), D13.15 (TC)
unnamed: D13.7 (CEP), D13.10 (CET), D14.15 (TC)
unnamed: B2.5, D13.9 (~PE), D13.12 (Q2), D14.9 (~PE)
unnamed: Q1.3 (C), R2.1, Y1.1
unnamed: Q1.1 (E), Q2.1 (E), R1.2
unnamed: Q2.2 (B), R4.2, Y1.2
unnamed: B2.10, Q2.3 (C), R3.1
PHI0: A2.1, B1.7 (2Q), B12.10, C1.2 (S1), D2.5; also elsewhere on the board
PHI1: B1.6 (~2Q); also elsewhere on the board
Q3: C1.13 (I3b), C2.9 (~PE), C2.12 (Q3); also elsewhere on the board
SOFT5: B1.1 (~CLR), B2.4, C2.1 (~MR), D11.1 (~MR), D12.1 (~MR), D13.1 (~MR), D13.5 (D2), D14.1 (~MR), D14.7 (CEP), D14.10 (CET); also elsewhere on the board
V0: D12.12 (Q2); also elsewhere on the board
VA: D13.6 (D3), D13.11 (Q3); also elsewhere on the board
VB: D12.14 (Q0); also elsewhere on the board
VC: D12.13 (Q1); also elsewhere on the board
~7M: B1.13 (4D), B1.14 (~4Q), B12.9; also elsewhere on the board
~CAS: B13.8, C2.13 (Q2); also elsewhere on the board
~LDPS: A2.3, D11.2 (CP), D12.2 (CP), D13.2 (CP), D14.2 (CP); also elsewhere on the board
~RAS: C2.7 (P3), C2.15 (Q0); also elsewhere on the board

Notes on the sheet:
Horizontal Video Address
14.3 MHz Clock
C1 Signals from RAM address decoding

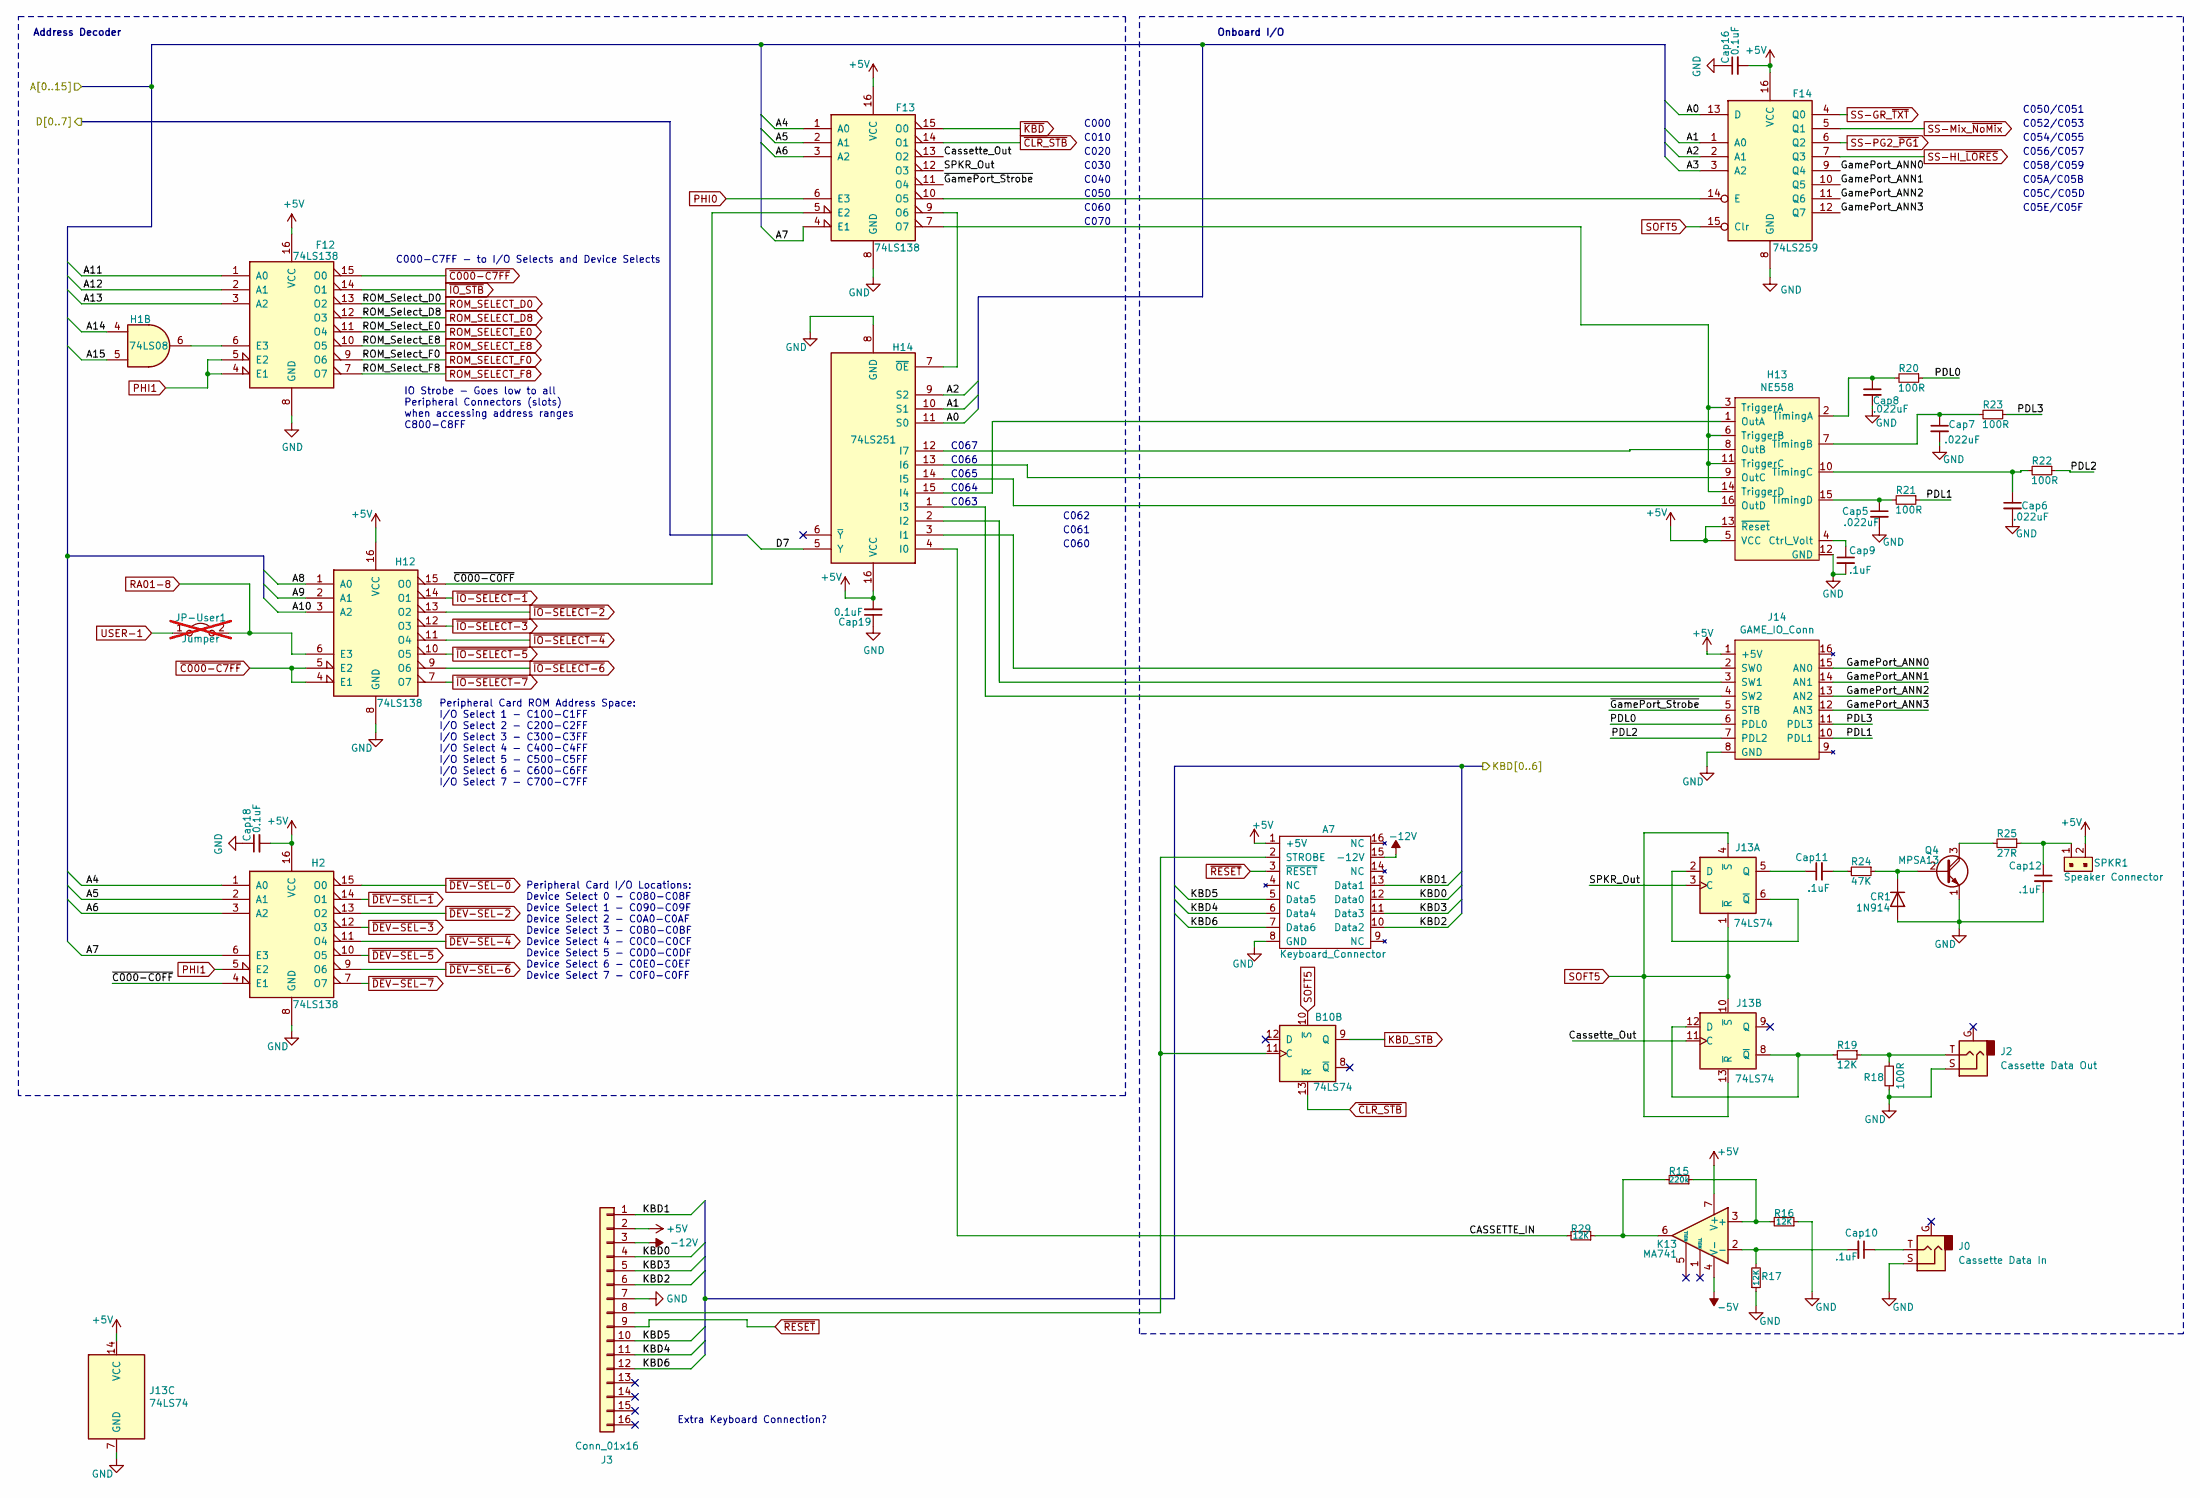
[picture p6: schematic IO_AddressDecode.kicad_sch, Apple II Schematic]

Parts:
A7: Keyboard_Connector; DIP-16_W7.62mm_Socket_LongPads
B10: 74LS74; DIP-14_W7.62mm
CR1: 1N914; D_DO-15_P10.16mm_Horizontal
Cap5, Cap6, Cap7, Cap8: .022uF; C_Disc_D5.0mm_W2.5mm_P5.00mm
Cap9, Cap10, Cap11, Cap12: .1uF; C_Disc_D5.0mm_W2.5mm_P5.00mm
Cap16, Cap18, Cap19: 0.1uF; C_Disc_D5.0mm_W2.5mm_P5.00mm
F12, F13: 74LS138; DIP-16_W7.62mm
F14: 74LS259; DIP-16_W7.62mm
H1: 74LS08; DIP-14_W7.62mm
H2, H12: 74LS138; DIP-16_W7.62mm
H13: NE558; DIP-16_W7.62mm
H14: 74LS251; DIP-16_W7.62mm
J0: Cassette Data In; AUDIO_mono; DigiKey CP-3502N-ND
J2: Cassette Data Out; AUDIO_mono; DigiKey CP-3502N-ND
J3: Conn_01x16; Keyboard Connector 16 Pin
J13: 74LS74; DIP-14_W7.62mm
J14: GAME_IO_Conn; DIP-16_W7.62mm_Socket_LongPads
JP-User1: Jumper; User-1; not fitted
K13: MA741; DIP-8_W7.62mm
Q4: MPSA13; TO-92; DigiKey KSP13BU-ND
R15: 220k; R_Axial_DIN0207_L6.3mm_D2.5mm_P10.16mm_Horizontal
R16, R17, R19, R29: 12K; R_Axial_DIN0207_L6.3mm_D2.5mm_P10.16mm_Horizontal
R18, R20, R21, R22, R23: 100R; R_Axial_DIN0207_L6.3mm_D2.5mm_P10.16mm_Horizontal
R24: 47K; R_Axial_DIN0207_L6.3mm_D2.5mm_P10.16mm_Horizontal
R25: 27R; R_Axial_DIN0207_L6.3mm_D2.5mm_P10.16mm_Horizontal
SPKR1: Speaker Connector; PinHeader_1x02_P2.54mm_Vertical; MPN 22-23-2021; Digi-Key_PN WM4200-ND

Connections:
+5V: A7.1 (+5V), Cap16.2, Cap18.2, Cap19.2, F12.16 (VCC), F13.16 (VCC), F14.16 (VCC), H2.16 (VCC), H12.16 (VCC), H13.5 (VCC), H13.13 (~Reset), H14.16 (VCC), J3.2, J13.14 (VCC), J14.1 (+5V), K13.7 (V+), SPKR1.2; also elsewhere on the board
-5V: K13.4 (V-); also elsewhere on the board
-12V: A7.15 (-12V), J3.3; also elsewhere on the board
/Address Decoder and Onboard IO/CASSETTE_IN: H14.4 (I0), R29.2
/Address Decoder and Onboard IO/Cassette_Out: F13.13 (O2), J13.11 (C)
/Address Decoder and Onboard IO/GamePort_ANN0: F14.9 (Q4), J14.15 (AN0)
/Address Decoder and Onboard IO/GamePort_ANN1: F14.10 (Q5), J14.14 (AN1)
/Address Decoder and Onboard IO/GamePort_ANN2: F14.11 (Q6), J14.13 (AN2)
/Address Decoder and Onboard IO/GamePort_ANN3: F14.12 (Q7), J14.12 (AN3)
/Address Decoder and Onboard IO/KBD0: A7.12 (Data0), J3.4; also elsewhere on the board
/Address Decoder and Onboard IO/KBD1: A7.13 (Data1), J3.1; also elsewhere on the board
/Address Decoder and Onboard IO/KBD2: A7.10 (Data2), J3.6; also elsewhere on the board
/Address Decoder and Onboard IO/KBD3: A7.11 (Data3), J3.5; also elsewhere on the board
/Address Decoder and Onboard IO/KBD4: A7.6 (Data4), J3.11; also elsewhere on the board
/Address Decoder and Onboard IO/KBD5: A7.5 (Data5), J3.10; also elsewhere on the board
/Address Decoder and Onboard IO/KBD6: A7.7 (Data6), J3.12; also elsewhere on the board
/Address Decoder and Onboard IO/PDL0: J14.6 (PDL0), R20.1
/Address Decoder and Onboard IO/PDL1: J14.10 (PDL1), R21.1
/Address Decoder and Onboard IO/PDL2: J14.7 (PDL2), R22.1
/Address Decoder and Onboard IO/PDL3: J14.11 (PDL3), R23.1
/Address Decoder and Onboard IO/SPKR_Out: F13.12 (O3), J13.3 (C)
/Address Decoder and Onboard IO/~C000-C0FF: F13.5 (E2), H2.4 (E1), H12.15 (O0)
/Address Decoder and Onboard IO/~GamePort_Strobe: F13.11 (O4), J14.5 (STB)
A0: F14.13 (D), H14.11 (S0); also elsewhere on the board
A1: F14.1 (A0), H14.10 (S1); also elsewhere on the board
A2: F14.2 (A1), H14.9 (S2); also elsewhere on the board
A3: F14.3 (A2); also elsewhere on the board
A4: F13.1 (A0), H2.1 (A0); also elsewhere on the board
A5: F13.2 (A1), H2.2 (A1); also elsewhere on the board
A6: F13.3 (A2), H2.3 (A2); also elsewhere on the board
A7: F13.4 (E1), H2.6 (E3); also elsewhere on the board
A8: H12.1 (A0); also elsewhere on the board
A9: H12.2 (A1); also elsewhere on the board
A10: H12.3 (A2); also elsewhere on the board
A11: F12.1 (A0); also elsewhere on the board
A12: F12.2 (A1); also elsewhere on the board
A13: F12.3 (A2); also elsewhere on the board
A14: H1.4; also elsewhere on the board
A15: H1.5; also elsewhere on the board
D7: H14.5 (Y); also elsewhere on the board
GND: A7.8 (GND), CR1.2 (A), Cap5.2, Cap6.2, Cap7.2, Cap8.2, Cap9.2, Cap12.2, Cap16.1, Cap18.1, Cap19.1, F12.8 (GND), F13.8 (GND), F14.8 (GND), H2.8 (GND), H12.8 (GND), H13.12 (GND), H14.8 (GND), J0.S, J2.S, J3.7, J13.7 (GND), J14.8 (GND), Q4.1 (E), R16.1, R17.1, R18.1; also elsewhere on the board
KBD_STB: B10.9 (Q); also elsewhere on the board
unnamed: A7.2 (STROBE), B10.11 (C), J3.8
unnamed: CR1.1 (K), Q4.2 (B), R24.1
unnamed: Cap10.1, J0.T
unnamed: Cap11.2, R24.2
unnamed: Cap12.1, R25.1, SPKR1.1
unnamed: F12.6 (E3), H1.6
unnamed: F13.10 (O5), F14.14 (E)
unnamed: F13.9 (O6), H14.7 (~OE)
unnamed: F13.7 (O7), H13.3 (TriggerA), H13.6 (TriggerB), H13.11 (TriggerC), H13.14 (TriggerD)
unnamed: Cap9.1, H13.4 (Ctrl_Volt)
unnamed: H13.1 (OutA), H14.15 (I4)
unnamed: H13.8 (OutB), H14.12 (I7)
unnamed: H13.9 (OutC), H14.13 (I6)
unnamed: H13.16 (OutD), H14.14 (I5)
unnamed: Cap8.1, H13.2 (TimingA), R20.2
unnamed: Cap7.1, H13.7 (TimingB), R23.2
unnamed: Cap6.1, H13.10 (TimingC), R22.2
unnamed: Cap5.1, H13.15 (TimingD), R21.2
unnamed: H14.3 (I1), J14.2 (SW0)
unnamed: H14.2 (I2), J14.3 (SW1)
unnamed: H14.1 (I3), J14.4 (SW2)
unnamed: J2.T, R18.2, R19.1
unnamed: J13.2 (D), J13.6 (~Q)
unnamed: Cap11.1, J13.5 (Q)
unnamed: J13.8 (~Q), J13.12 (D), R19.2
unnamed: K13.3 (+), R15.1, R16.2
unnamed: Cap10.2, K13.2 (-), R17.2
unnamed: K13.6, R15.2, R29.1
unnamed: Q4.3 (C), R25.2
PHI0: F13.6 (E3); also elsewhere on the board
PHI1: F12.4 (E1), F12.5 (E2), H2.5 (E2); also elsewhere on the board
RA01-8: H12.6 (E3), JP-User1.2 (B); also elsewhere on the board
ROM_SELECT_D0: F12.13 (O2); also elsewhere on the board
ROM_SELECT_D8: F12.12 (O3); also elsewhere on the board
ROM_SELECT_E0: F12.11 (O4); also elsewhere on the board
ROM_SELECT_E8: F12.10 (O5); also elsewhere on the board
ROM_SELECT_F0: F12.9 (O6); also elsewhere on the board
ROM_SELECT_F8: F12.7 (O7); also elsewhere on the board
SOFT5: B10.10 (~S), F14.15 (Clr), J13.1 (~R), J13.4 (~S), J13.10 (~S), J13.13 (~R); also elsewhere on the board
SS-GR_~TXT: F14.4 (Q0); also elsewhere on the board
SS-HI_~LORES: F14.7 (Q3); also elsewhere on the board
SS-Mix_~NoMix: F14.5 (Q1); also elsewhere on the board
SS-PG2_~PG1: F14.6 (Q2); also elsewhere on the board
USER-1: JP-User1.1 (A); also elsewhere on the board
~C000-C7FF: F12.15 (O0), H12.4 (E1), H12.5 (E2)
~CLR_STB: B10.13 (~R), F13.14 (O1)
~DEV-SEL-0: H2.15 (O0); also elsewhere on the board
~DEV-SEL-1: H2.14 (O1); also elsewhere on the board
~DEV-SEL-2: H2.13 (O2); also elsewhere on the board
~DEV-SEL-3: H2.12 (O3); also elsewhere on the board
~DEV-SEL-4: H2.11 (O4); also elsewhere on the board
~DEV-SEL-5: H2.10 (O5); also elsewhere on the board
~DEV-SEL-6: H2.9 (O6); also elsewhere on the board
~DEV-SEL-7: H2.7 (O7); also elsewhere on the board
~IO-SELECT-1: H12.14 (O1); also elsewhere on the board
~IO-SELECT-2: H12.13 (O2); also elsewhere on the board
~IO-SELECT-3: H12.12 (O3); also elsewhere on the board
~IO-SELECT-4: H12.11 (O4); also elsewhere on the board
~IO-SELECT-5: H12.10 (O5); also elsewhere on the board
~IO-SELECT-6: H12.9 (O6); also elsewhere on the board
~IO-SELECT-7: H12.7 (O7); also elsewhere on the board
~IO_STB: F12.14 (O1); also elsewhere on the board
~KBD: F13.15 (O0); also elsewhere on the board
~RESET: A7.3 (~RESET), J3.9; also elsewhere on the board

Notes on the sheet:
C050/C051
C060
C05E/C05F
C063
C054/C055
C050
C070
C052/C053
IO Strobe - Goes low to all Peripheral Connectors (slots) when accessing address ranges C800-C8FF
C066
C010
C000
Onboard I/O
C061
C05A/C05B
Address Decoder
C062
C05C/C05D
C040
Peripheral Card I/O Locations: Device Select 0 - C080-C08F Device Select 1 - C090-C09F Device Select 2 - C0A0-C0AF Device Select 3 - C0B0-C0BF Device Select 4 - C0C0-C0CF Device Select 5 - C0D0-C0DF Device Select 6 - C0E0-C0EF Device Select 7 - C0F0-C0FF
C064
C030
Extra Keyboard Connection?
C056/C057
C065
C058/C059
C000-C7FF - to I/O Selects and Device Selects
C067
C020
Peripheral Card ROM Address Space: I/O Select 1 - C100-C1FF I/O Select 2 - C200-C2FF I/O Select 3 - C300-C3FF I/O Select 4 - C400-C4FF I/O Select 5 - C500-C5FF I/O Select 6 - C600-C6FF I/O Select 7 - C700-C7FF

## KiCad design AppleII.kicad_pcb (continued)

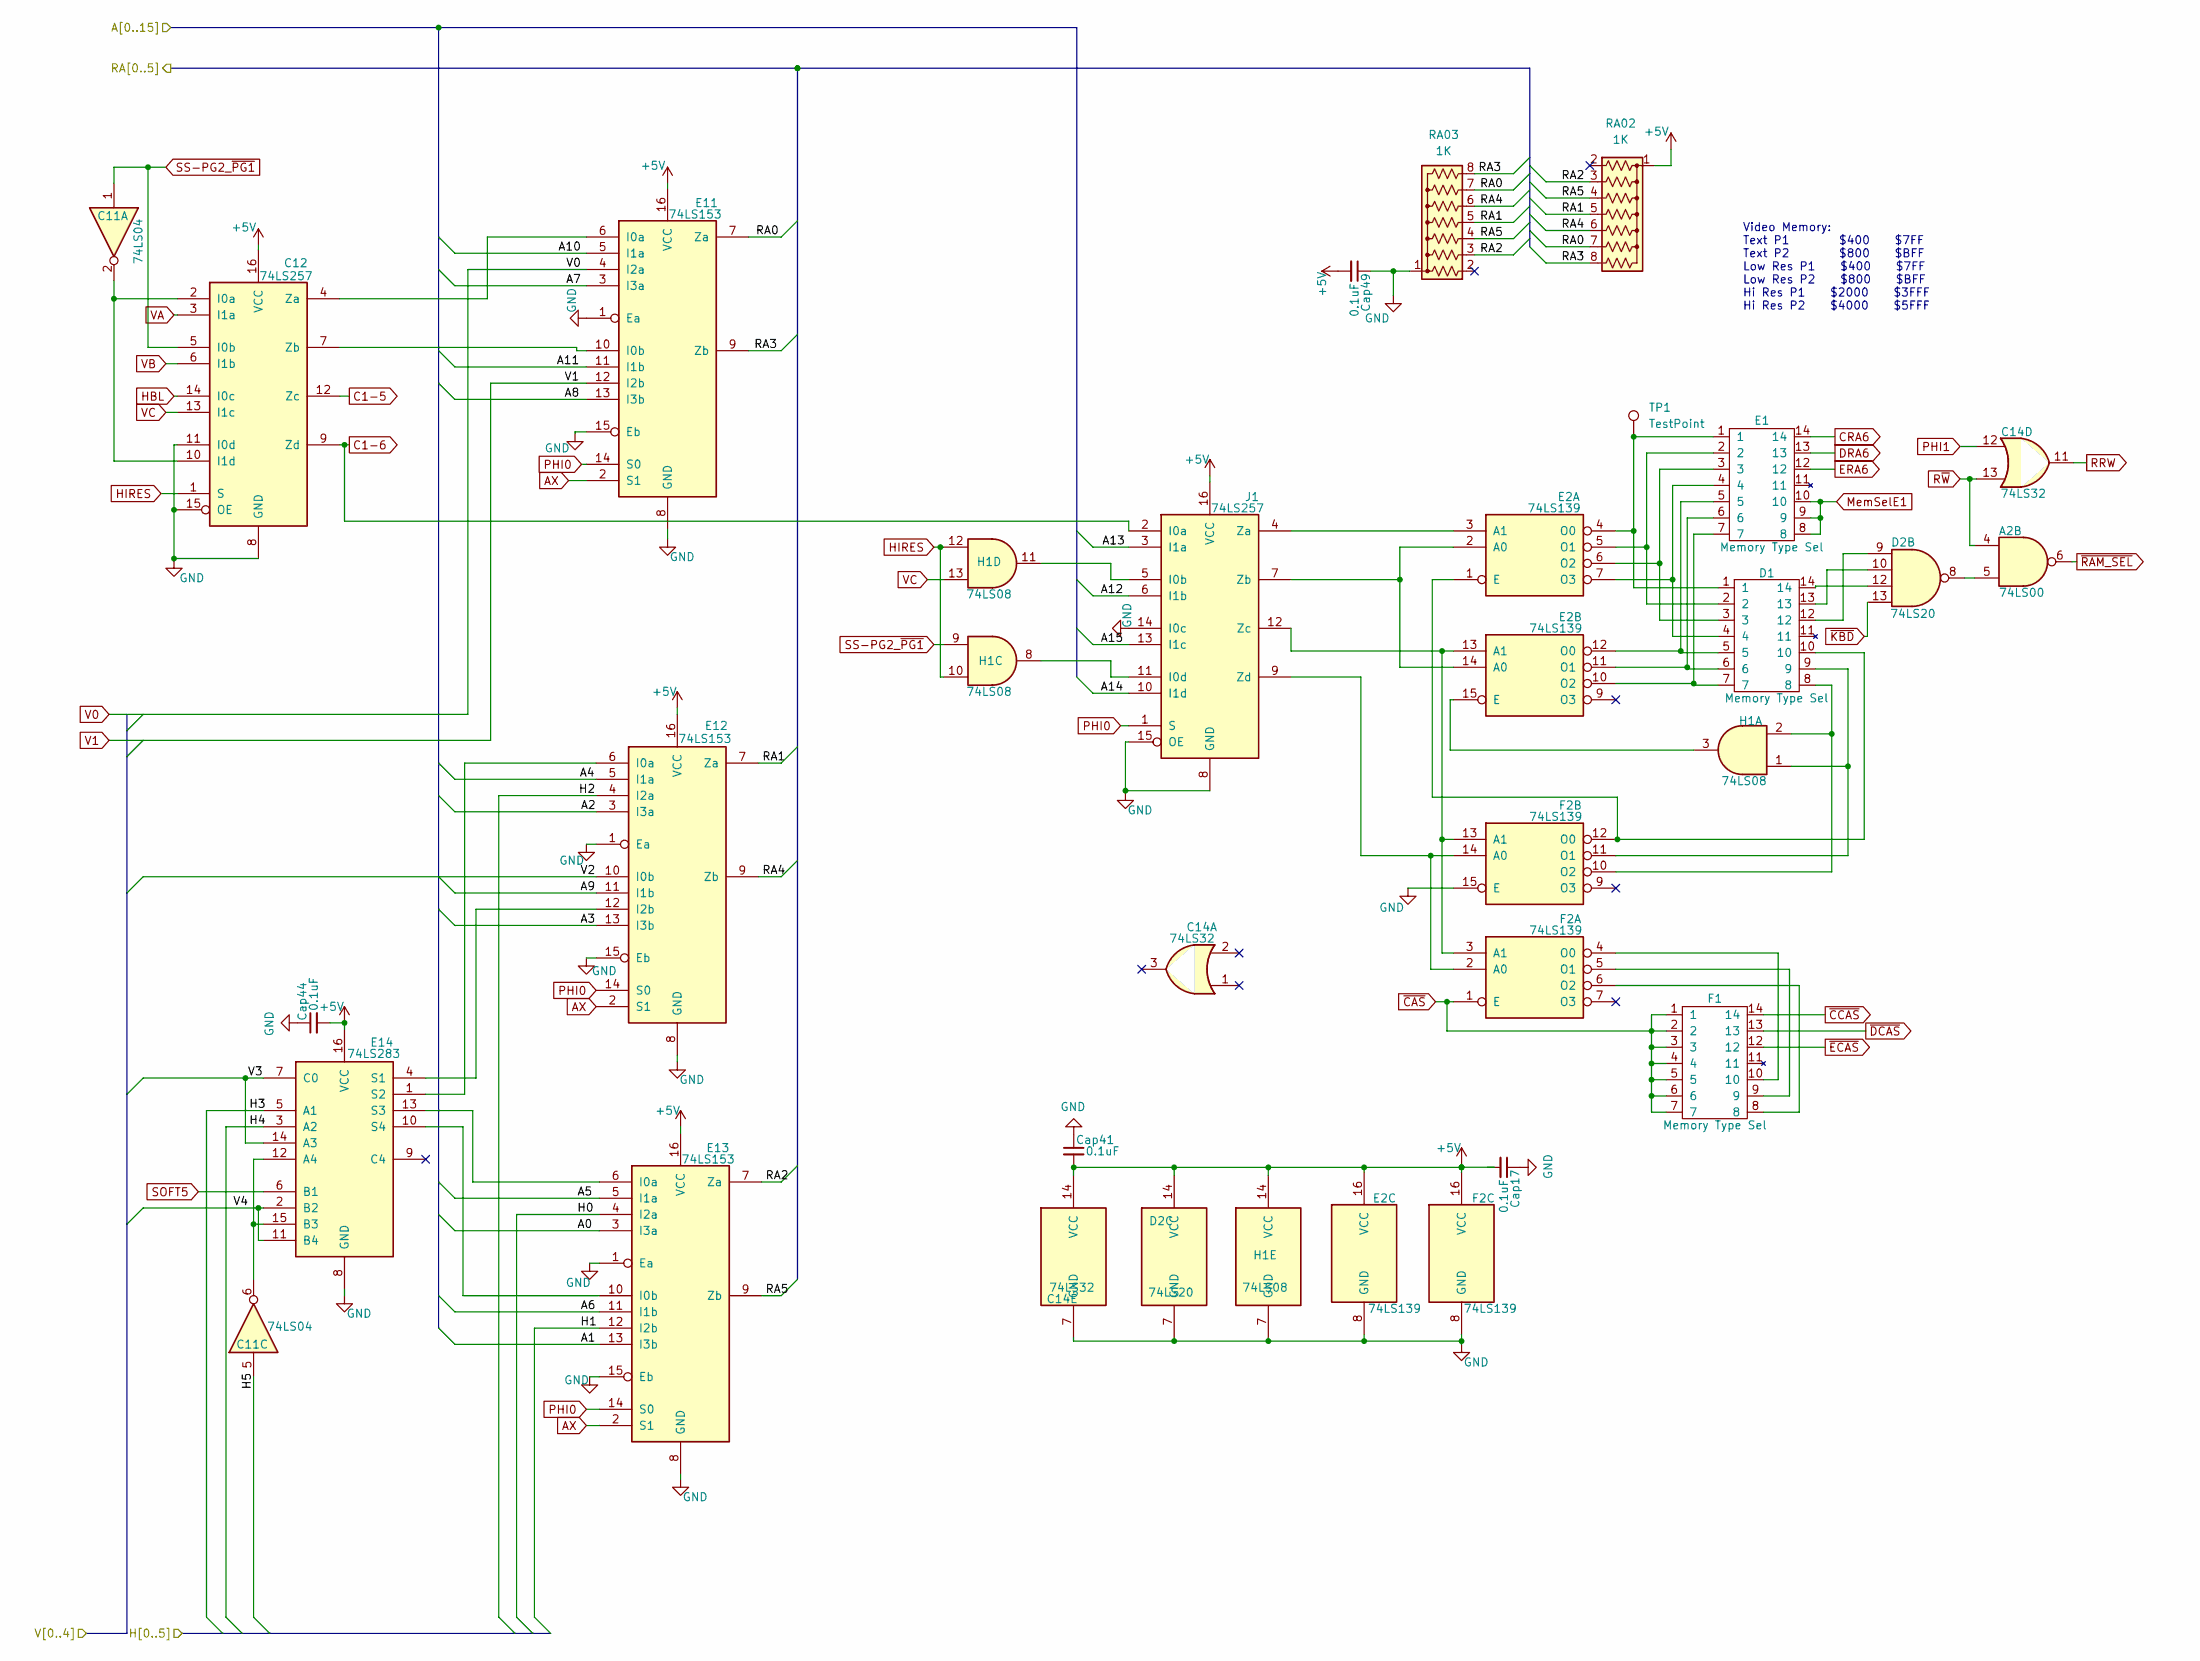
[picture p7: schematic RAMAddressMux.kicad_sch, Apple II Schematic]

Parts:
A2: 74LS00; DIP-14_W7.62mm
C11: 74LS04; DIP-14_W7.62mm
C12: 74LS257; DIP-16_W7.62mm
C14: 74LS32; DIP-14_W7.62mm
Cap17, Cap41, Cap44, Cap49: 0.1uF; C_Disc_D5.0mm_W2.5mm_P5.00mm
D1: Memory Type Sel; DIP-14_W7.62mm
D2: 74LS20; DIP-14_W7.62mm
E1: Memory Type Sel; DIP-14_W7.62mm
E2: 74LS139; DIP-16_W7.62mm
E11, E12, E13: 74LS153; DIP-16_W7.62mm
E14: 74LS283; DIP-16_W7.62mm
F1: Memory Type Sel; DIP-14_W7.62mm
F2: 74LS139; DIP-16_W7.62mm
H1: 74LS08; DIP-14_W7.62mm
J1: 74LS257; DIP-16_W7.62mm
RA02, RA03: 1K; R_Array_SIP8
TP1: TestPoint

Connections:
+5V: C12.16 (VCC), C14.14 (VCC), Cap17.2, Cap41.2, Cap44.2, Cap49.2, D2.14 (VCC), E2.16 (VCC), E11.16 (VCC), E12.16 (VCC), E13.16 (VCC), E14.16 (VCC), F2.16 (VCC), H1.14 (VCC), J1.16 (VCC), RA02.1 (common); also elsewhere on the board
/Clock Generation/H0: E13.4 (I2a); also elsewhere on the board
/Clock Generation/H1: E13.12 (I2b); also elsewhere on the board
/Clock Generation/H2: E12.4 (I2a); also elsewhere on the board
/Clock Generation/H3: E14.5 (A1); also elsewhere on the board
/Clock Generation/H4: E14.3 (A2); also elsewhere on the board
/Clock Generation/H5: C11.5; also elsewhere on the board
/Clock Generation/V1: E11.12 (I2b); also elsewhere on the board
/Clock Generation/V2: E12.10 (I0b); also elsewhere on the board
/Clock Generation/V3: E14.7 (C0), E14.14 (A3); also elsewhere on the board
/Clock Generation/V4: E14.2 (B2), E14.11 (B4); also elsewhere on the board
A0: E13.3 (I3a); also elsewhere on the board
A1: E13.13 (I3b); also elsewhere on the board
A2: E12.3 (I3a); also elsewhere on the board
A3: E12.13 (I3b); also elsewhere on the board
A4: E12.5 (I1a); also elsewhere on the board
A5: E13.5 (I1a); also elsewhere on the board
A6: E13.11 (I1b); also elsewhere on the board
A7: E11.3 (I3a); also elsewhere on the board
A8: E11.13 (I3b); also elsewhere on the board
A9: E12.11 (I1b); also elsewhere on the board
A10: E11.5 (I1a); also elsewhere on the board
A11: E11.11 (I1b); also elsewhere on the board
A12: J1.6 (I1b); also elsewhere on the board
A13: J1.3 (I1a); also elsewhere on the board
A14: J1.10 (I1d); also elsewhere on the board
A15: J1.13 (I1c); also elsewhere on the board
AX: E11.2 (S1), E12.2 (S1), E13.2 (S1); also elsewhere on the board
C1-5: C12.12 (Zc); also elsewhere on the board
C1-6: C12.9 (Zd), J1.2 (I0a); also elsewhere on the board
CRA6: E1.14; also elsewhere on the board
DRA6: E1.13; also elsewhere on the board
ERA6: E1.12; also elsewhere on the board
GND: C12.8 (GND), C12.11 (I0d), C12.15 (OE), C14.7 (GND), Cap17.1, Cap41.1, Cap44.1, Cap49.1, D2.7 (GND), E2.8 (GND), E11.1 (Ea), E11.8 (GND), E11.15 (Eb), E12.1 (Ea), E12.8 (GND), E12.15 (Eb), E13.1 (Ea), E13.8 (GND), E13.15 (Eb), E14.8 (GND), F2.8 (GND), F2.15 (E), H1.7 (GND), J1.8 (GND), J1.14 (I0c), J1.15 (OE), RA03.1 (common); also elsewhere on the board
HBL: C12.14 (I0c); also elsewhere on the board
HIRES: C12.1 (S), H1.10, H1.12; also elsewhere on the board
MemSelE1: E1.8, E1.9, E1.10; also elsewhere on the board
unnamed: A2.5, D2.8
unnamed: C11.2, C12.2 (I0a), C12.10 (I1d)
unnamed: C12.4 (Za), E11.6 (I0a)
unnamed: C12.7 (Zb), E11.10 (I0b)
unnamed: D1.12, D2.9
unnamed: D1.13, D2.10
unnamed: D1.14, D2.12
unnamed: E2.2 (A0), E2.14 (A0), J1.7 (Zb)
unnamed: E2.3 (A1), J1.4 (Za)
unnamed: D1.10, E2.1 (E), F2.12 (O0)
unnamed: D1.1, E1.1, E2.4 (O0), TP1.1
unnamed: D1.2, E1.2, E2.5 (O1)
unnamed: D1.3, E1.3, E2.6 (O2)
unnamed: D1.4, E1.4, E2.7 (O3)
unnamed: E2.13 (A1), F2.3 (A1), F2.13 (A1), J1.12 (Zc)
unnamed: E2.15 (E), H1.3
unnamed: D1.5, E1.5, E2.12 (O0)
unnamed: D1.6, E1.6, E2.11 (O1)
unnamed: D1.7, E1.7, E2.10 (O2)
unnamed: E12.6 (I0a), E14.1 (S2)
unnamed: E12.12 (I2b), E14.4 (S1)
unnamed: E13.6 (I0a), E14.13 (S3)
unnamed: E13.10 (I0b), E14.10 (S4)
unnamed: C11.6, E14.12 (A4), E14.15 (B3)
unnamed: F2.2 (A0), F2.14 (A0), J1.9 (Zd)
unnamed: F1.10, F2.4 (O0)
unnamed: F1.9, F2.5 (O1)
unnamed: F1.8, F2.6 (O2)
unnamed: D1.9, F2.11 (O1), H1.1
unnamed: D1.8, F2.10 (O2), H1.2
unnamed: H1.11, J1.5 (I0b)
unnamed: H1.8, J1.11 (I0d)
PHI0: E11.14 (S0), E12.14 (S0), E13.14 (S0), J1.1 (S); also elsewhere on the board
PHI1: C14.12; also elsewhere on the board
RA0: E11.7 (Za), RA02.7 (R6), RA03.7 (R6); also elsewhere on the board
RA1: E12.7 (Za), RA02.5 (R4), RA03.5 (R4); also elsewhere on the board
RA2: E13.7 (Za), RA02.3 (R2), RA03.3 (R2); also elsewhere on the board
RA3: E11.9 (Zb), RA02.8 (R7), RA03.8 (R7); also elsewhere on the board
RA4: E12.9 (Zb), RA02.6 (R5), RA03.6 (R5); also elsewhere on the board
RA5: E13.9 (Zb), RA02.4 (R3), RA03.4 (R3); also elsewhere on the board
RRW: C14.11; also elsewhere on the board
R~W: A2.4, C14.13; also elsewhere on the board
SOFT5: E14.6 (B1); also elsewhere on the board
SS-PG2_~PG1: C11.1, C12.5 (I0b), H1.9; also elsewhere on the board
V0: E11.4 (I2a); also elsewhere on the board
VA: C12.3 (I1a); also elsewhere on the board
VB: C12.6 (I1b); also elsewhere on the board
VC: C12.13 (I1c), H1.13; also elsewhere on the board
~CAS: F1.1, F1.2, F1.3, F1.4, F1.5, F1.6, F1.7, F2.1 (E); also elsewhere on the board
~CCAS: F1.14; also elsewhere on the board
~DCAS: F1.13; also elsewhere on the board
~ECAS: F1.12; also elsewhere on the board
~KBD: D2.13; also elsewhere on the board
~RAM_SEL: A2.6; also elsewhere on the board

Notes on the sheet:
Video Memory: Text P1 $400 $7FF Text P2 $800 $BFF Low Res P1 $400 $7FF Low Res P2 $800 $BFF Hi Res P1 $2000 $3FFF Hi Res P2 $4000 $5FFF

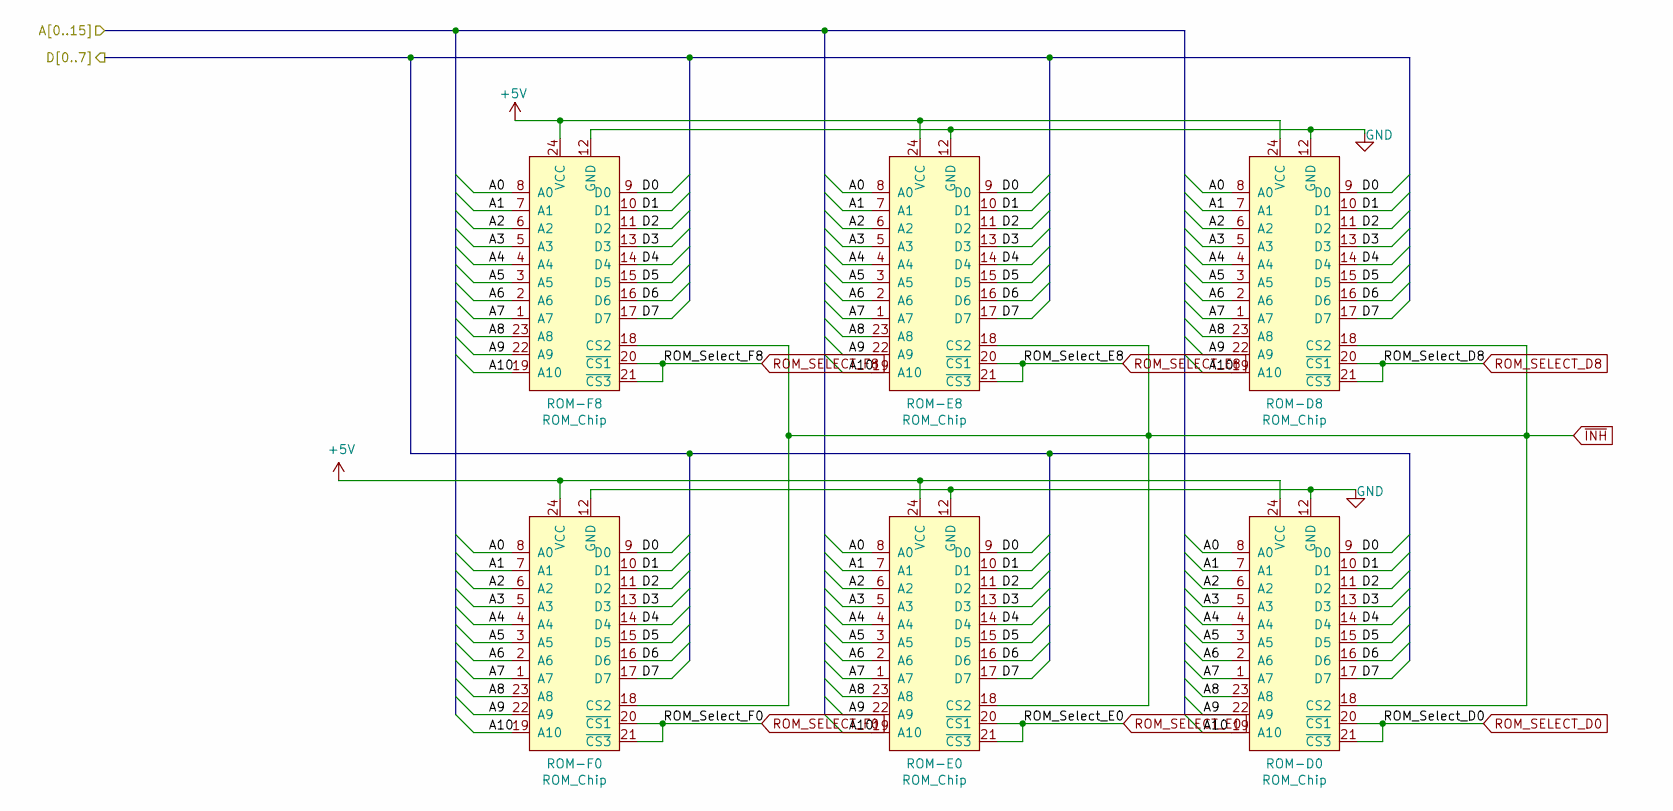
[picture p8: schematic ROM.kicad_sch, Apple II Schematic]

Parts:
ROM-D0, ROM-D8: ROM_Chip; DIP-24_W15.24mm
ROM-E0, ROM-E8: ROM_Chip; DIP-24_W15.24mm
ROM-F0, ROM-F8: ROM_Chip; DIP-24_W15.24mm

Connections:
+5V: ROM-D0.24 (VCC), ROM-D8.24 (VCC), ROM-E0.24 (VCC), ROM-E8.24 (VCC), ROM-F0.24 (VCC), ROM-F8.24 (VCC); also elsewhere on the board
A0: ROM-D0.8 (A0), ROM-D8.8 (A0), ROM-E0.8 (A0), ROM-E8.8 (A0), ROM-F0.8 (A0), ROM-F8.8 (A0); also elsewhere on the board
A1: ROM-D0.7 (A1), ROM-D8.7 (A1), ROM-E0.7 (A1), ROM-E8.7 (A1), ROM-F0.7 (A1), ROM-F8.7 (A1); also elsewhere on the board
A2: ROM-D0.6 (A2), ROM-D8.6 (A2), ROM-E0.6 (A2), ROM-E8.6 (A2), ROM-F0.6 (A2), ROM-F8.6 (A2); also elsewhere on the board
A3: ROM-D0.5 (A3), ROM-D8.5 (A3), ROM-E0.5 (A3), ROM-E8.5 (A3), ROM-F0.5 (A3), ROM-F8.5 (A3); also elsewhere on the board
A4: ROM-D0.4 (A4), ROM-D8.4 (A4), ROM-E0.4 (A4), ROM-E8.4 (A4), ROM-F0.4 (A4), ROM-F8.4 (A4); also elsewhere on the board
A5: ROM-D0.3 (A5), ROM-D8.3 (A5), ROM-E0.3 (A5), ROM-E8.3 (A5), ROM-F0.3 (A5), ROM-F8.3 (A5); also elsewhere on the board
A6: ROM-D0.2 (A6), ROM-D8.2 (A6), ROM-E0.2 (A6), ROM-E8.2 (A6), ROM-F0.2 (A6), ROM-F8.2 (A6); also elsewhere on the board
A7: ROM-D0.1 (A7), ROM-D8.1 (A7), ROM-E0.1 (A7), ROM-E8.1 (A7), ROM-F0.1 (A7), ROM-F8.1 (A7); also elsewhere on the board
A8: ROM-D0.23 (A8), ROM-D8.23 (A8), ROM-E0.23 (A8), ROM-E8.23 (A8), ROM-F0.23 (A8), ROM-F8.23 (A8); also elsewhere on the board
A9: ROM-D0.22 (A9), ROM-D8.22 (A9), ROM-E0.22 (A9), ROM-E8.22 (A9), ROM-F0.22 (A9), ROM-F8.22 (A9); also elsewhere on the board
A10: ROM-D0.19 (A10), ROM-D8.19 (A10), ROM-E0.19 (A10), ROM-E8.19 (A10), ROM-F0.19 (A10), ROM-F8.19 (A10); also elsewhere on the board
D0: ROM-D0.9 (D0), ROM-D8.9 (D0), ROM-E0.9 (D0), ROM-E8.9 (D0), ROM-F0.9 (D0), ROM-F8.9 (D0); also elsewhere on the board
D1: ROM-D0.10 (D1), ROM-D8.10 (D1), ROM-E0.10 (D1), ROM-E8.10 (D1), ROM-F0.10 (D1), ROM-F8.10 (D1); also elsewhere on the board
D2: ROM-D0.11 (D2), ROM-D8.11 (D2), ROM-E0.11 (D2), ROM-E8.11 (D2), ROM-F0.11 (D2), ROM-F8.11 (D2); also elsewhere on the board
D3: ROM-D0.13 (D3), ROM-D8.13 (D3), ROM-E0.13 (D3), ROM-E8.13 (D3), ROM-F0.13 (D3), ROM-F8.13 (D3); also elsewhere on the board
D4: ROM-D0.14 (D4), ROM-D8.14 (D4), ROM-E0.14 (D4), ROM-E8.14 (D4), ROM-F0.14 (D4), ROM-F8.14 (D4); also elsewhere on the board
D5: ROM-D0.15 (D5), ROM-D8.15 (D5), ROM-E0.15 (D5), ROM-E8.15 (D5), ROM-F0.15 (D5), ROM-F8.15 (D5); also elsewhere on the board
D6: ROM-D0.16 (D6), ROM-D8.16 (D6), ROM-E0.16 (D6), ROM-E8.16 (D6), ROM-F0.16 (D6), ROM-F8.16 (D6); also elsewhere on the board
D7: ROM-D0.17 (D7), ROM-D8.17 (D7), ROM-E0.17 (D7), ROM-E8.17 (D7), ROM-F0.17 (D7), ROM-F8.17 (D7); also elsewhere on the board
GND: ROM-D0.12 (GND), ROM-D8.12 (GND), ROM-E0.12 (GND), ROM-E8.12 (GND), ROM-F0.12 (GND), ROM-F8.12 (GND); also elsewhere on the board
ROM_SELECT_D0: ROM-D0.20 (~CS1), ROM-D0.21 (~CS3); also elsewhere on the board
ROM_SELECT_D8: ROM-D8.20 (~CS1), ROM-D8.21 (~CS3); also elsewhere on the board
ROM_SELECT_E0: ROM-E0.20 (~CS1), ROM-E0.21 (~CS3); also elsewhere on the board
ROM_SELECT_E8: ROM-E8.20 (~CS1), ROM-E8.21 (~CS3); also elsewhere on the board
ROM_SELECT_F0: ROM-F0.20 (~CS1), ROM-F0.21 (~CS3); also elsewhere on the board
ROM_SELECT_F8: ROM-F8.20 (~CS1), ROM-F8.21 (~CS3); also elsewhere on the board
~INH: ROM-D0.18 (CS2), ROM-D8.18 (CS2), ROM-E0.18 (CS2), ROM-E8.18 (CS2), ROM-F0.18 (CS2), ROM-F8.18 (CS2); also elsewhere on the board

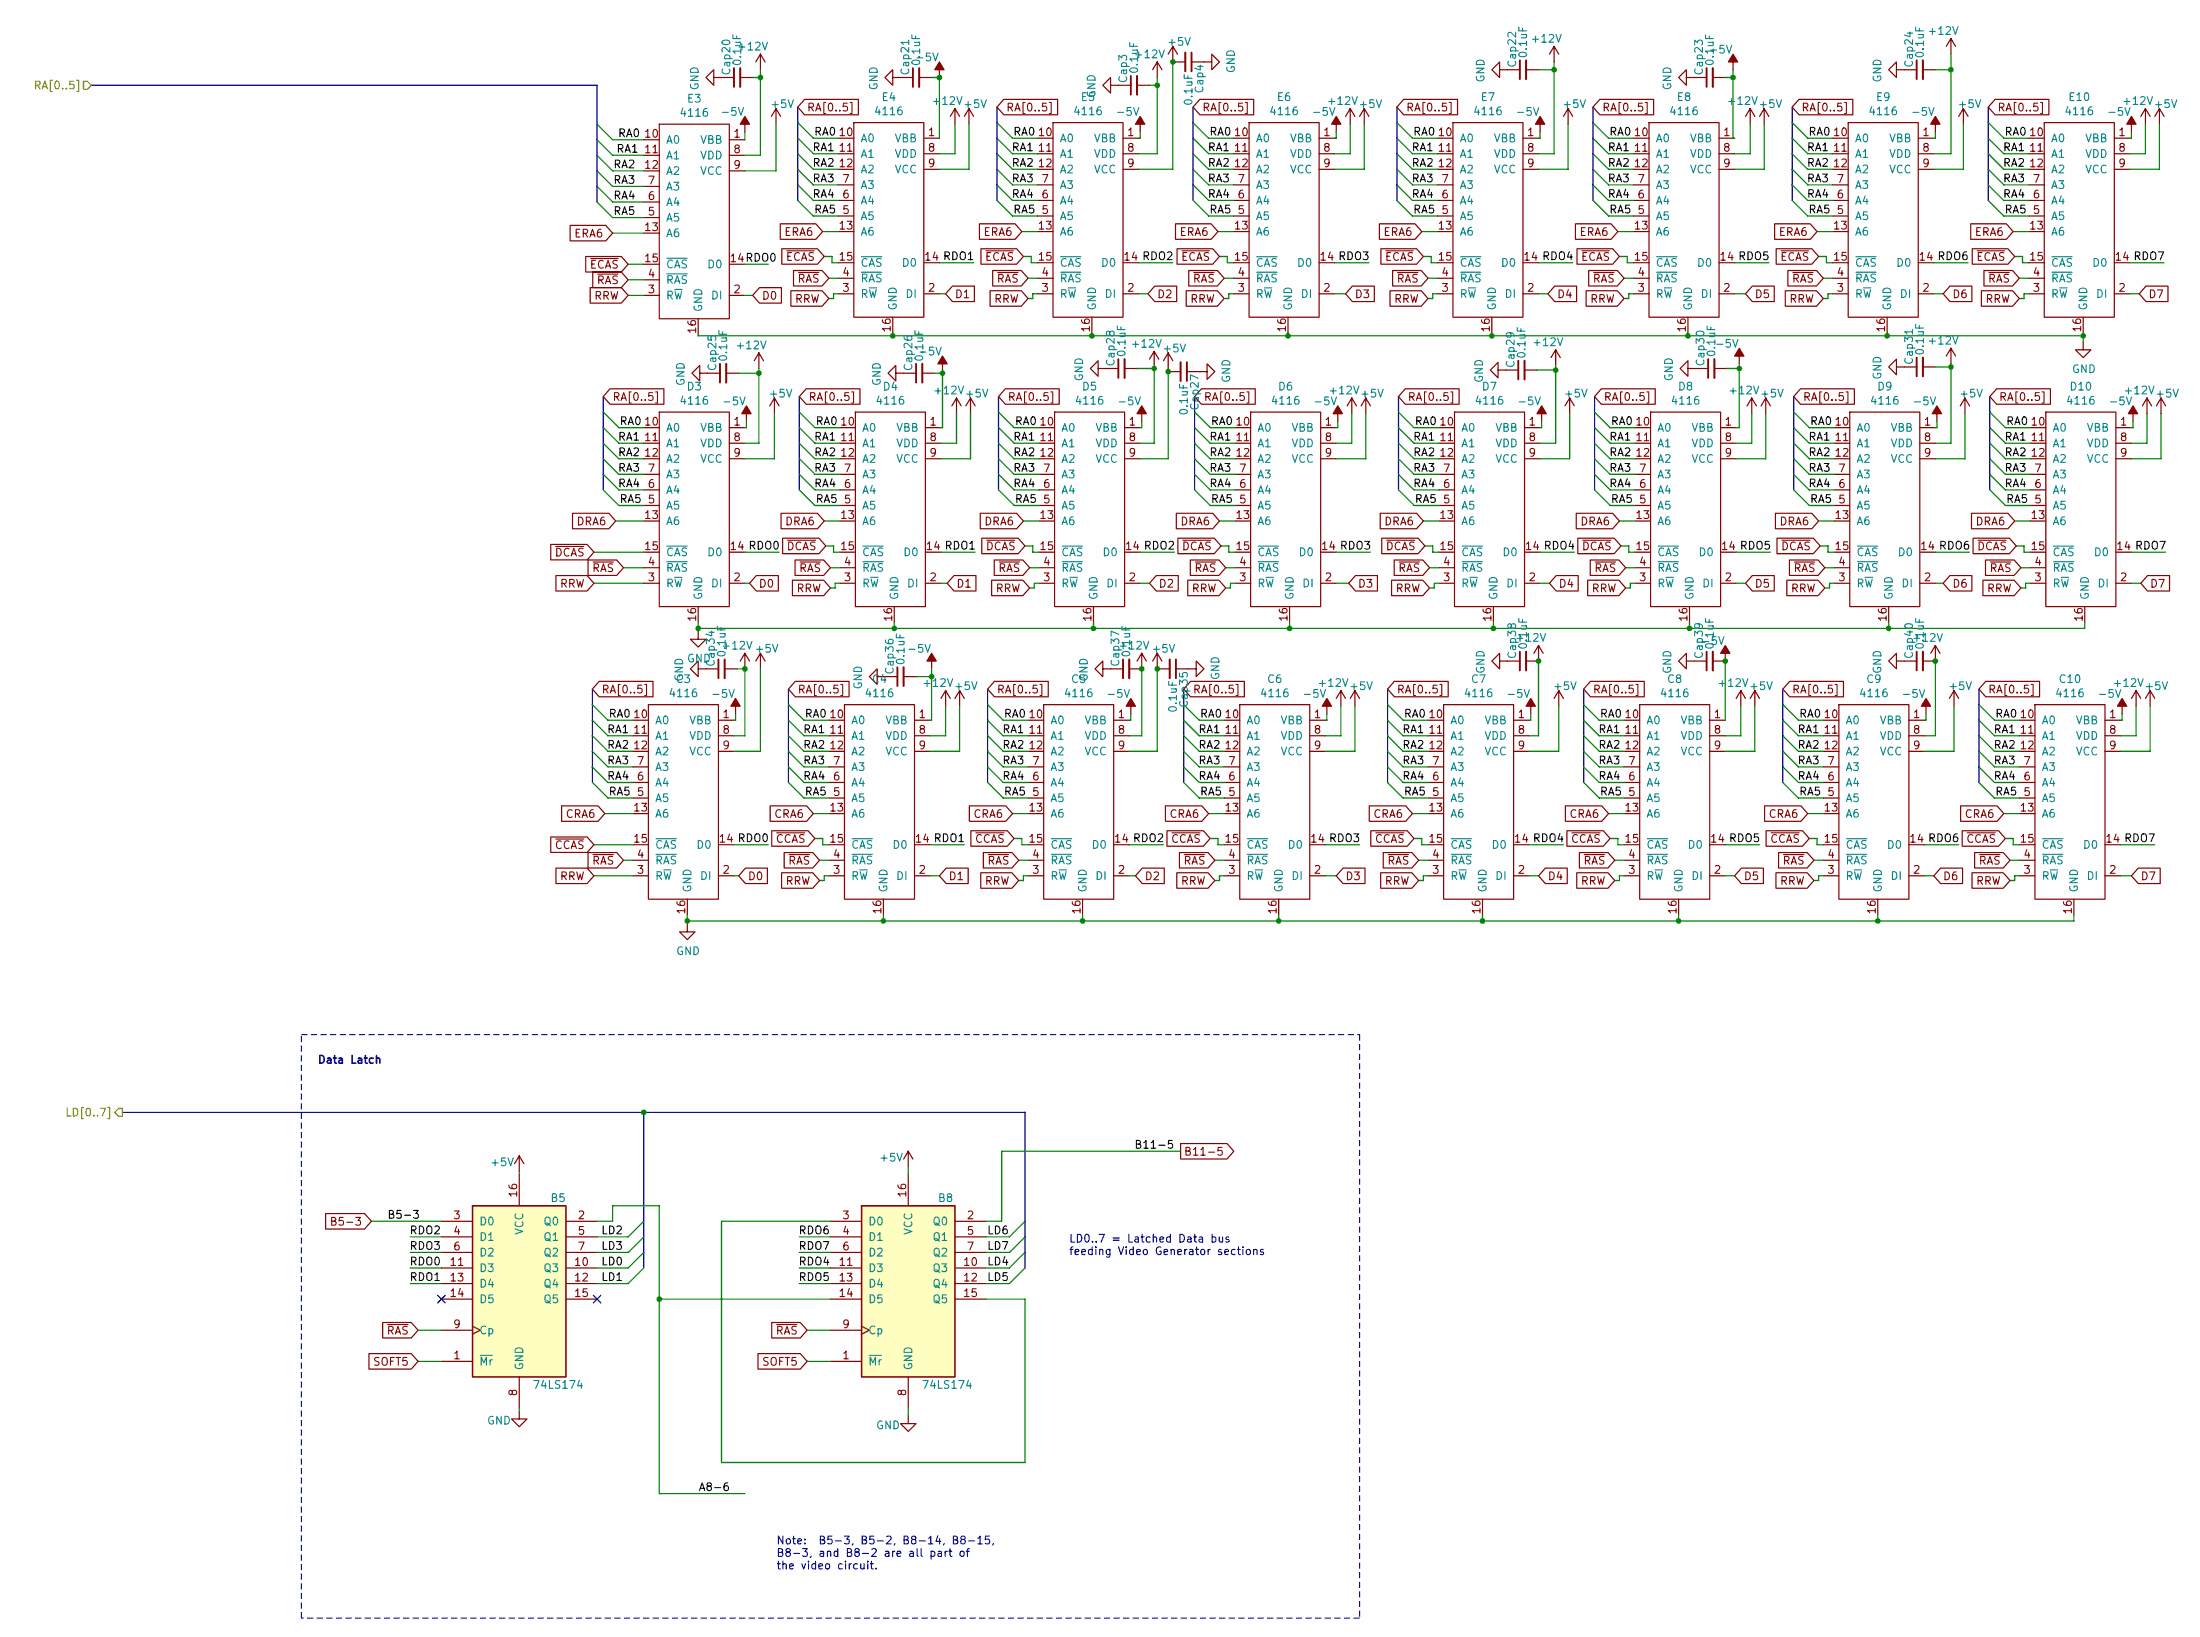
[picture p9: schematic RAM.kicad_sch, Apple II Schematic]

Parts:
B5, B8: 74LS174; DIP-16_W7.62mm
C3, C4, C5, C6, C7, C8, C9, C10: 4116; DIP-16_W7.62mm
Cap3, Cap4, Cap20, Cap21, Cap22, Cap23, Cap24, Cap25, Cap26, Cap27, Cap28, Cap29, Cap30, Cap31, Cap34, Cap35, Cap36, Cap37, Cap38, Cap39, Cap40: 0.1uF; C_Disc_D5.0mm_W2.5mm_P5.00mm
D3, D4, D5, D6, D7, D8, D9, D10: 4116; DIP-16_W7.62mm
E3, E4, E5, E6, E7, E8, E9, E10: 4116; DIP-16_W7.62mm

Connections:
+5V: B5.16 (VCC), B8.16 (VCC), C3.9 (VCC), C4.9 (VCC), C5.9 (VCC), C6.9 (VCC), C7.9 (VCC), C8.9 (VCC), C9.9 (VCC), C10.9 (VCC), Cap4.2, Cap27.2, Cap35.2, D3.9 (VCC), D4.9 (VCC), D5.9 (VCC), D6.9 (VCC), D7.9 (VCC), D8.9 (VCC), D9.9 (VCC), D10.9 (VCC), E3.9 (VCC), E4.9 (VCC), E5.9 (VCC), E6.9 (VCC), E7.9 (VCC), E8.9 (VCC), E9.9 (VCC), E10.9 (VCC); also elsewhere on the board
+12V: C3.8 (VDD), C4.8 (VDD), C5.8 (VDD), C6.8 (VDD), C7.8 (VDD), C8.8 (VDD), C9.8 (VDD), C10.8 (VDD), Cap3.2, Cap20.2, Cap22.2, Cap24.2, Cap25.2, Cap28.2, Cap29.2, Cap31.2, Cap34.2, Cap37.2, Cap38.2, Cap40.2, D3.8 (VDD), D4.8 (VDD), D5.8 (VDD), D6.8 (VDD), D7.8 (VDD), D8.8 (VDD), D9.8 (VDD), D10.8 (VDD), E3.8 (VDD), E4.8 (VDD), E5.8 (VDD), E6.8 (VDD), E7.8 (VDD), E8.8 (VDD), E9.8 (VDD), E10.8 (VDD); also elsewhere on the board
-5V: C3.1 (VBB), C4.1 (VBB), C5.1 (VBB), C6.1 (VBB), C7.1 (VBB), C8.1 (VBB), C9.1 (VBB), C10.1 (VBB), Cap21.2, Cap23.2, Cap26.2, Cap30.2, Cap36.2, Cap39.2, D3.1 (VBB), D4.1 (VBB), D5.1 (VBB), D6.1 (VBB), D7.1 (VBB), D8.1 (VBB), D9.1 (VBB), D10.1 (VBB), E3.1 (VBB), E4.1 (VBB), E5.1 (VBB), E6.1 (VBB), E7.1 (VBB), E8.1 (VBB), E9.1 (VBB), E10.1 (VBB); also elsewhere on the board
/CPU Tranceiver Driver and Data MUX/LD0: B5.10 (Q3); also elsewhere on the board
/CPU Tranceiver Driver and Data MUX/LD1: B5.12 (Q4); also elsewhere on the board
/CPU Tranceiver Driver and Data MUX/LD2: B5.5 (Q1); also elsewhere on the board
/CPU Tranceiver Driver and Data MUX/LD3: B5.7 (Q2); also elsewhere on the board
/CPU Tranceiver Driver and Data MUX/LD4: B8.10 (Q3); also elsewhere on the board
/CPU Tranceiver Driver and Data MUX/LD5: B8.12 (Q4); also elsewhere on the board
/CPU Tranceiver Driver and Data MUX/LD6: B8.5 (Q1); also elsewhere on the board
/CPU Tranceiver Driver and Data MUX/LD7: B8.7 (Q2); also elsewhere on the board
/RAM and Data Latch/A8-6: B5.2 (Q0), B8.14 (D5)
/RAM and Data Latch/RDO0: B5.11 (D3), C3.14 (D0), D3.14 (D0), E3.14 (D0)
/RAM and Data Latch/RDO1: B5.13 (D4), C4.14 (D0), D4.14 (D0), E4.14 (D0)
/RAM and Data Latch/RDO2: B5.4 (D1), C5.14 (D0), D5.14 (D0), E5.14 (D0)
/RAM and Data Latch/RDO3: B5.6 (D2), C6.14 (D0), D6.14 (D0), E6.14 (D0)
/RAM and Data Latch/RDO4: B8.11 (D3), C7.14 (D0), D7.14 (D0), E7.14 (D0)
/RAM and Data Latch/RDO5: B8.13 (D4), C8.14 (D0), D8.14 (D0), E8.14 (D0)
/RAM and Data Latch/RDO6: B8.4 (D1), C9.14 (D0), D9.14 (D0), E9.14 (D0)
/RAM and Data Latch/RDO7: B8.6 (D2), C10.14 (D0), D10.14 (D0), E10.14 (D0)
B5-3: B5.3 (D0); also elsewhere on the board
B11-5: B8.2 (Q0); also elsewhere on the board
CRA6: C3.13 (A6), C4.13 (A6), C5.13 (A6), C6.13 (A6), C7.13 (A6), C8.13 (A6), C9.13 (A6), C10.13 (A6); also elsewhere on the board
D0: C3.2 (DI), D3.2 (DI), E3.2 (DI); also elsewhere on the board
D1: C4.2 (DI), D4.2 (DI), E4.2 (DI); also elsewhere on the board
D2: C5.2 (DI), D5.2 (DI), E5.2 (DI); also elsewhere on the board
D3: C6.2 (DI), D6.2 (DI), E6.2 (DI); also elsewhere on the board
D4: C7.2 (DI), D7.2 (DI), E7.2 (DI); also elsewhere on the board
D5: C8.2 (DI), D8.2 (DI), E8.2 (DI); also elsewhere on the board
D6: C9.2 (DI), D9.2 (DI), E9.2 (DI); also elsewhere on the board
D7: C10.2 (DI), D10.2 (DI), E10.2 (DI); also elsewhere on the board
DRA6: D3.13 (A6), D4.13 (A6), D5.13 (A6), D6.13 (A6), D7.13 (A6), D8.13 (A6), D9.13 (A6), D10.13 (A6); also elsewhere on the board
ERA6: E3.13 (A6), E4.13 (A6), E5.13 (A6), E6.13 (A6), E7.13 (A6), E8.13 (A6), E9.13 (A6), E10.13 (A6); also elsewhere on the board
GND: B5.8 (GND), B8.8 (GND), C3.16 (GND), C4.16 (GND), C5.16 (GND), C6.16 (GND), C7.16 (GND), C8.16 (GND), C9.16 (GND), C10.16 (GND), Cap3.1, Cap4.1, Cap20.1, Cap21.1, Cap22.1, Cap23.1, Cap24.1, Cap25.1, Cap26.1, Cap27.1, Cap28.1, Cap29.1, Cap30.1, Cap31.1, Cap34.1, Cap35.1, Cap36.1, Cap37.1, Cap38.1, Cap39.1, Cap40.1, D3.16 (GND), D4.16 (GND), D5.16 (GND), D6.16 (GND), D7.16 (GND), D8.16 (GND), D9.16 (GND), D10.16 (GND), E3.16 (GND), E4.16 (GND), E5.16 (GND), E6.16 (GND), E7.16 (GND), E8.16 (GND), E9.16 (GND), E10.16 (GND); also elsewhere on the board
unnamed: B8.3 (D0), B8.15 (Q5)
RA0: C3.10 (A0), C4.10 (A0), C5.10 (A0), C6.10 (A0), C7.10 (A0), C8.10 (A0), C9.10 (A0), C10.10 (A0), D3.10 (A0), D4.10 (A0), D5.10 (A0), D6.10 (A0), D7.10 (A0), D8.10 (A0), D9.10 (A0), D10.10 (A0), E3.10 (A0), E4.10 (A0), E5.10 (A0), E6.10 (A0), E7.10 (A0), E8.10 (A0), E9.10 (A0), E10.10 (A0); also elsewhere on the board
RA1: C3.11 (A1), C4.11 (A1), C5.11 (A1), C6.11 (A1), C7.11 (A1), C8.11 (A1), C9.11 (A1), C10.11 (A1), D3.11 (A1), D4.11 (A1), D5.11 (A1), D6.11 (A1), D7.11 (A1), D8.11 (A1), D9.11 (A1), D10.11 (A1), E3.11 (A1), E4.11 (A1), E5.11 (A1), E6.11 (A1), E7.11 (A1), E8.11 (A1), E9.11 (A1), E10.11 (A1); also elsewhere on the board
RA2: C3.12 (A2), C4.12 (A2), C5.12 (A2), C6.12 (A2), C7.12 (A2), C8.12 (A2), C9.12 (A2), C10.12 (A2), D3.12 (A2), D4.12 (A2), D5.12 (A2), D6.12 (A2), D7.12 (A2), D8.12 (A2), D9.12 (A2), D10.12 (A2), E3.12 (A2), E4.12 (A2), E5.12 (A2), E6.12 (A2), E7.12 (A2), E8.12 (A2), E9.12 (A2), E10.12 (A2); also elsewhere on the board
RA3: C3.7 (A3), C4.7 (A3), C5.7 (A3), C6.7 (A3), C7.7 (A3), C8.7 (A3), C9.7 (A3), C10.7 (A3), D3.7 (A3), D4.7 (A3), D5.7 (A3), D6.7 (A3), D7.7 (A3), D8.7 (A3), D9.7 (A3), D10.7 (A3), E3.7 (A3), E4.7 (A3), E5.7 (A3), E6.7 (A3), E7.7 (A3), E8.7 (A3), E9.7 (A3), E10.7 (A3); also elsewhere on the board
RA4: C3.6 (A4), C4.6 (A4), C5.6 (A4), C6.6 (A4), C7.6 (A4), C8.6 (A4), C9.6 (A4), C10.6 (A4), D3.6 (A4), D4.6 (A4), D5.6 (A4), D6.6 (A4), D7.6 (A4), D8.6 (A4), D9.6 (A4), D10.6 (A4), E3.6 (A4), E4.6 (A4), E5.6 (A4), E6.6 (A4), E7.6 (A4), E8.6 (A4), E9.6 (A4), E10.6 (A4); also elsewhere on the board
RA5: C3.5 (A5), C4.5 (A5), C5.5 (A5), C6.5 (A5), C7.5 (A5), C8.5 (A5), C9.5 (A5), C10.5 (A5), D3.5 (A5), D4.5 (A5), D5.5 (A5), D6.5 (A5), D7.5 (A5), D8.5 (A5), D9.5 (A5), D10.5 (A5), E3.5 (A5), E4.5 (A5), E5.5 (A5), E6.5 (A5), E7.5 (A5), E8.5 (A5), E9.5 (A5), E10.5 (A5); also elsewhere on the board
RRW: C3.3 (R~W), C4.3 (R~W), C5.3 (R~W), C6.3 (R~W), C7.3 (R~W), C8.3 (R~W), C9.3 (R~W), C10.3 (R~W), D3.3 (R~W), D4.3 (R~W), D5.3 (R~W), D6.3 (R~W), D7.3 (R~W), D8.3 (R~W), D9.3 (R~W), D10.3 (R~W), E3.3 (R~W), E4.3 (R~W), E5.3 (R~W), E6.3 (R~W), E7.3 (R~W), E8.3 (R~W), E9.3 (R~W), E10.3 (R~W); also elsewhere on the board
SOFT5: B5.1 (~Mr), B8.1 (~Mr); also elsewhere on the board
~CCAS: C3.15 (~CAS), C4.15 (~CAS), C5.15 (~CAS), C6.15 (~CAS), C7.15 (~CAS), C8.15 (~CAS), C9.15 (~CAS), C10.15 (~CAS); also elsewhere on the board
~DCAS: D3.15 (~CAS), D4.15 (~CAS), D5.15 (~CAS), D6.15 (~CAS), D7.15 (~CAS), D8.15 (~CAS), D9.15 (~CAS), D10.15 (~CAS); also elsewhere on the board
~ECAS: E3.15 (~CAS), E4.15 (~CAS), E5.15 (~CAS), E6.15 (~CAS), E7.15 (~CAS), E8.15 (~CAS), E9.15 (~CAS), E10.15 (~CAS); also elsewhere on the board
~RAS: B5.9 (Cp), B8.9 (Cp), C3.4 (~RAS), C4.4 (~RAS), C5.4 (~RAS), C6.4 (~RAS), C7.4 (~RAS), C8.4 (~RAS), C9.4 (~RAS), C10.4 (~RAS), D3.4 (~RAS), D4.4 (~RAS), D5.4 (~RAS), D6.4 (~RAS), D7.4 (~RAS), D8.4 (~RAS), D9.4 (~RAS), D10.4 (~RAS), E3.4 (~RAS), E4.4 (~RAS), E5.4 (~RAS), E6.4 (~RAS), E7.4 (~RAS), E8.4 (~RAS), E9.4 (~RAS), E10.4 (~RAS); also elsewhere on the board

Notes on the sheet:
LD0..7 = Latched Data bus feeding Video Generator sections
Data Latch
Note: B5-3, B5-2, B8-14, B8-15, B8-3, and B8-2 are all part of the video circuit.

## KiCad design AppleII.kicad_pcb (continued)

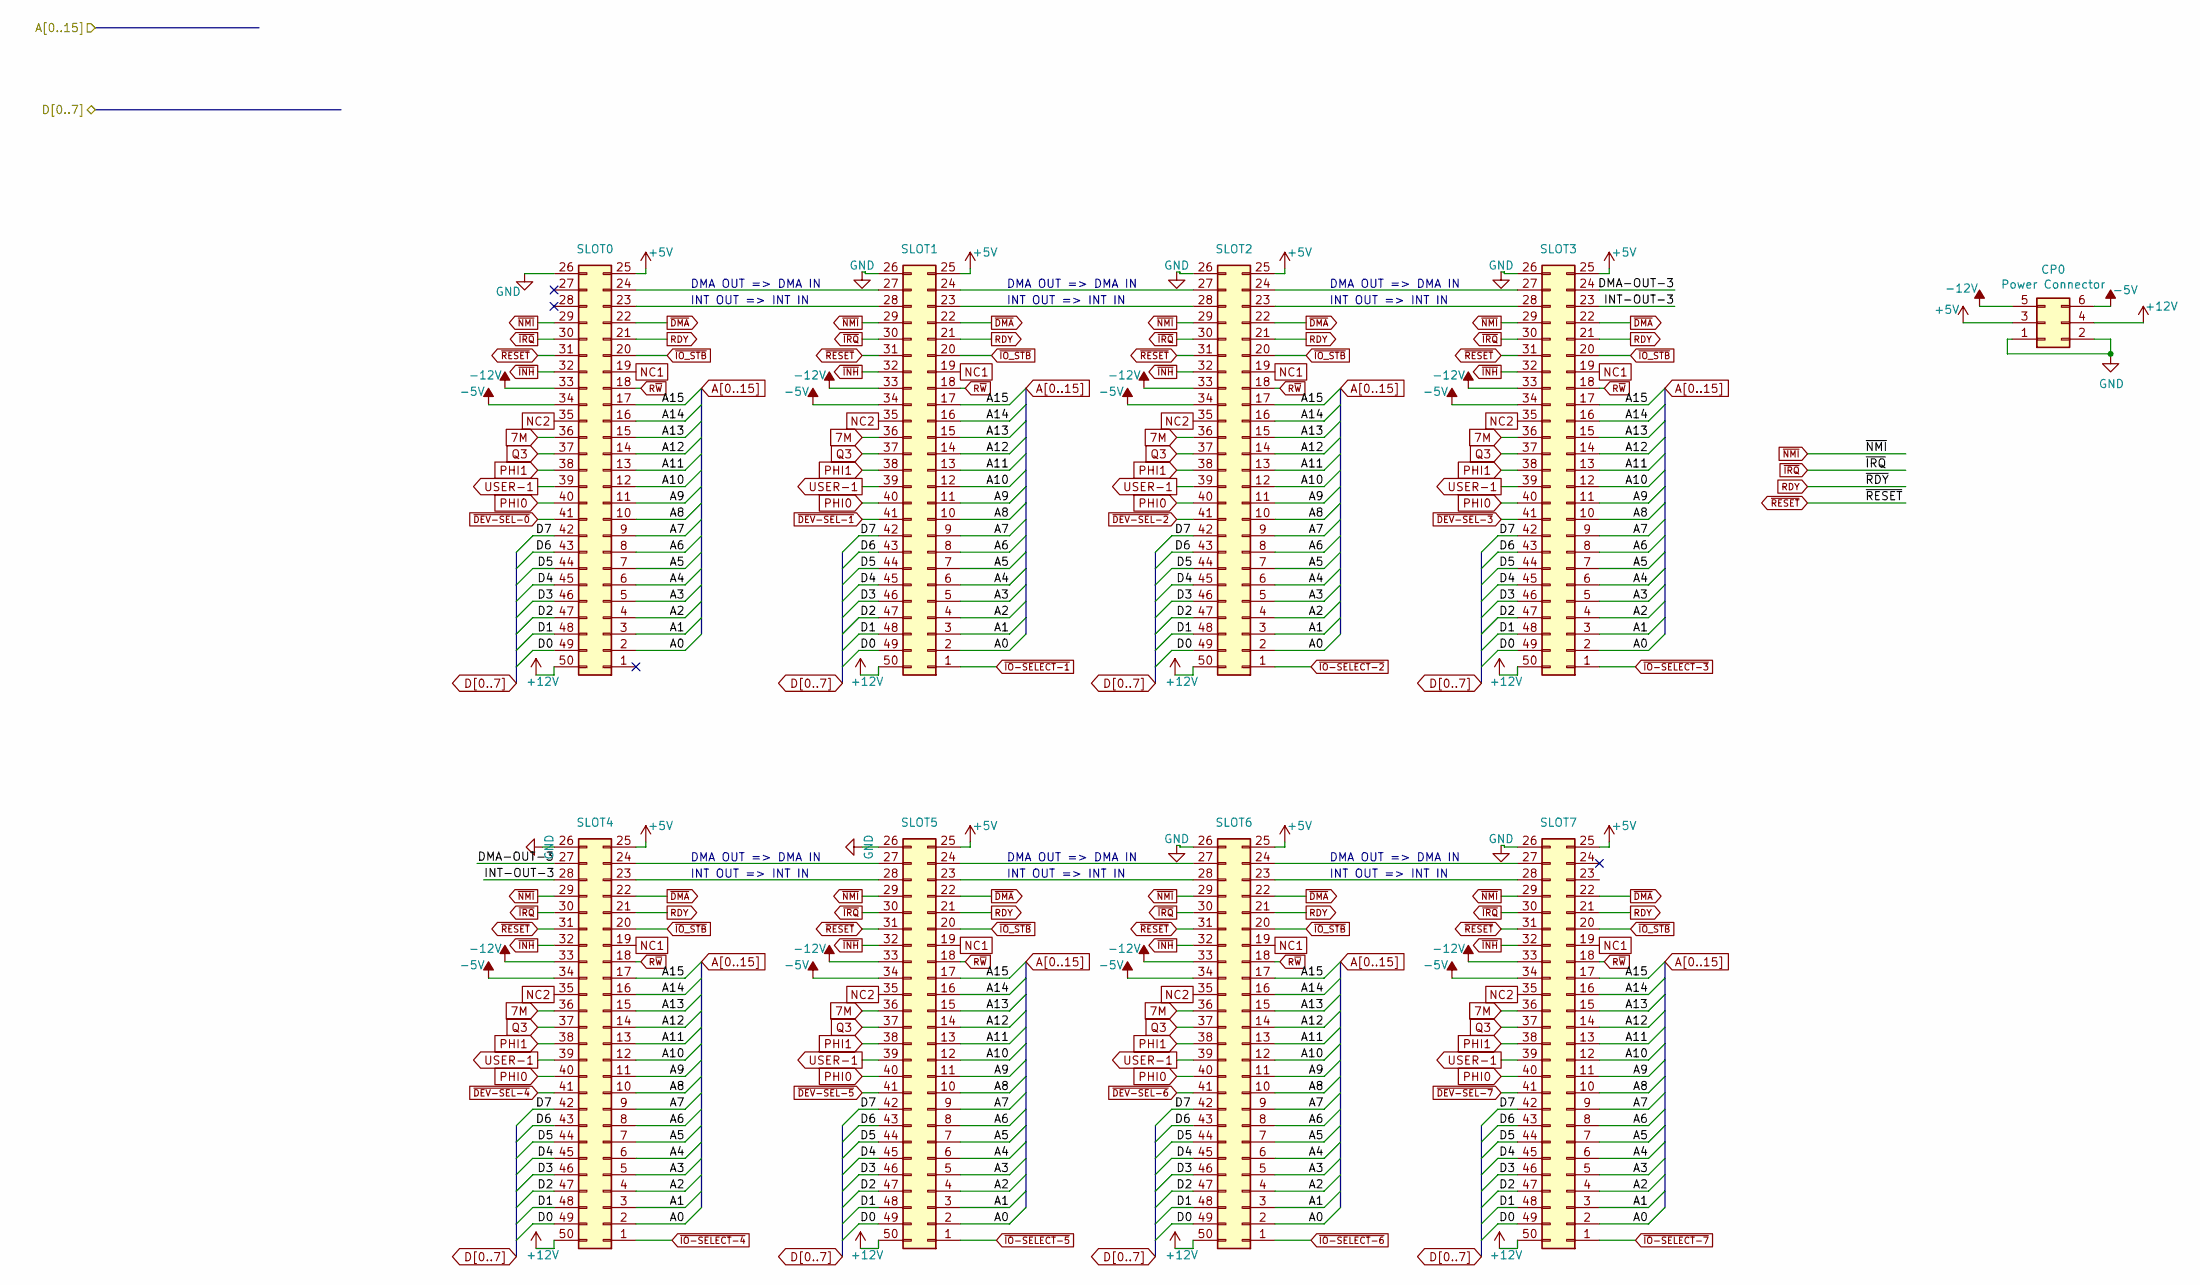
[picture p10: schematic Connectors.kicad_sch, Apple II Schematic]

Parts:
CP0: Power Connector; POWER; DigiKey A14226-ND
SLOT0: 50 pin slot; Standard_Edge_Connector; DigiKey A31718-ND
SLOT1, SLOT2, SLOT3, SLOT4, SLOT5, SLOT6, SLOT7: 50 pin slot; Standard_Edge_Connector

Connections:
7M: SLOT0.36, SLOT1.36, SLOT2.36, SLOT3.36, SLOT4.36, SLOT5.36, SLOT6.36, SLOT7.36; also elsewhere on the board
+5V: CP0.3, SLOT0.25, SLOT1.25, SLOT2.25, SLOT3.25, SLOT4.25, SLOT5.25, SLOT6.25, SLOT7.25; also elsewhere on the board
+12V: CP0.4, SLOT0.50, SLOT1.50, SLOT2.50, SLOT3.50, SLOT4.50, SLOT5.50, SLOT6.50, SLOT7.50; also elsewhere on the board
-5V: CP0.6, SLOT0.34, SLOT1.34, SLOT2.34, SLOT3.34, SLOT4.34, SLOT5.34, SLOT6.34, SLOT7.34; also elsewhere on the board
-12V: CP0.5, SLOT0.33, SLOT1.33, SLOT2.33, SLOT3.33, SLOT4.33, SLOT5.33, SLOT6.33, SLOT7.33; also elsewhere on the board
/Connectors/DMA-OUT-3: SLOT3.24, SLOT4.27
/Connectors/INT-OUT-3: SLOT3.23, SLOT4.28
A0: SLOT0.2, SLOT1.2, SLOT2.2, SLOT3.2, SLOT4.2, SLOT5.2, SLOT6.2, SLOT7.2; also elsewhere on the board
A1: SLOT0.3, SLOT1.3, SLOT2.3, SLOT3.3, SLOT4.3, SLOT5.3, SLOT6.3, SLOT7.3; also elsewhere on the board
A2: SLOT0.4, SLOT1.4, SLOT2.4, SLOT3.4, SLOT4.4, SLOT5.4, SLOT6.4, SLOT7.4; also elsewhere on the board
A3: SLOT0.5, SLOT1.5, SLOT2.5, SLOT3.5, SLOT4.5, SLOT5.5, SLOT6.5, SLOT7.5; also elsewhere on the board
A4: SLOT0.6, SLOT1.6, SLOT2.6, SLOT3.6, SLOT4.6, SLOT5.6, SLOT6.6, SLOT7.6; also elsewhere on the board
A5: SLOT0.7, SLOT1.7, SLOT2.7, SLOT3.7, SLOT4.7, SLOT5.7, SLOT6.7, SLOT7.7; also elsewhere on the board
A6: SLOT0.8, SLOT1.8, SLOT2.8, SLOT3.8, SLOT4.8, SLOT5.8, SLOT6.8, SLOT7.8; also elsewhere on the board
A7: SLOT0.9, SLOT1.9, SLOT2.9, SLOT3.9, SLOT4.9, SLOT5.9, SLOT6.9, SLOT7.9; also elsewhere on the board
A8: SLOT0.10, SLOT1.10, SLOT2.10, SLOT3.10, SLOT4.10, SLOT5.10, SLOT6.10, SLOT7.10; also elsewhere on the board
A9: SLOT0.11, SLOT1.11, SLOT2.11, SLOT3.11, SLOT4.11, SLOT5.11, SLOT6.11, SLOT7.11; also elsewhere on the board
A10: SLOT0.12, SLOT1.12, SLOT2.12, SLOT3.12, SLOT4.12, SLOT5.12, SLOT6.12, SLOT7.12; also elsewhere on the board
A11: SLOT0.13, SLOT1.13, SLOT2.13, SLOT3.13, SLOT4.13, SLOT5.13, SLOT6.13, SLOT7.13; also elsewhere on the board
A12: SLOT0.14, SLOT1.14, SLOT2.14, SLOT3.14, SLOT4.14, SLOT5.14, SLOT6.14, SLOT7.14; also elsewhere on the board
A13: SLOT0.15, SLOT1.15, SLOT2.15, SLOT3.15, SLOT4.15, SLOT5.15, SLOT6.15, SLOT7.15; also elsewhere on the board
A14: SLOT0.16, SLOT1.16, SLOT2.16, SLOT3.16, SLOT4.16, SLOT5.16, SLOT6.16, SLOT7.16; also elsewhere on the board
A15: SLOT0.17, SLOT1.17, SLOT2.17, SLOT3.17, SLOT4.17, SLOT5.17, SLOT6.17, SLOT7.17; also elsewhere on the board
D0: SLOT0.49, SLOT1.49, SLOT2.49, SLOT3.49, SLOT4.49, SLOT5.49, SLOT6.49, SLOT7.49; also elsewhere on the board
D1: SLOT0.48, SLOT1.48, SLOT2.48, SLOT3.48, SLOT4.48, SLOT5.48, SLOT6.48, SLOT7.48; also elsewhere on the board
D2: SLOT0.47, SLOT1.47, SLOT2.47, SLOT3.47, SLOT4.47, SLOT5.47, SLOT6.47, SLOT7.47; also elsewhere on the board
D3: SLOT0.46, SLOT1.46, SLOT2.46, SLOT3.46, SLOT4.46, SLOT5.46, SLOT6.46, SLOT7.46; also elsewhere on the board
D4: SLOT0.45, SLOT1.45, SLOT2.45, SLOT3.45, SLOT4.45, SLOT5.45, SLOT6.45, SLOT7.45; also elsewhere on the board
D5: SLOT0.44, SLOT1.44, SLOT2.44, SLOT3.44, SLOT4.44, SLOT5.44, SLOT6.44, SLOT7.44; also elsewhere on the board
D6: SLOT0.43, SLOT1.43, SLOT2.43, SLOT3.43, SLOT4.43, SLOT5.43, SLOT6.43, SLOT7.43; also elsewhere on the board
D7: SLOT0.42, SLOT1.42, SLOT2.42, SLOT3.42, SLOT4.42, SLOT5.42, SLOT6.42, SLOT7.42; also elsewhere on the board
GND: CP0.1, CP0.2, SLOT0.26, SLOT1.26, SLOT2.26, SLOT3.26, SLOT4.26, SLOT5.26, SLOT6.26, SLOT7.26; also elsewhere on the board
NC1: SLOT0.19, SLOT1.19, SLOT2.19, SLOT3.19, SLOT4.19, SLOT5.19, SLOT6.19, SLOT7.19
NC2: SLOT0.35, SLOT1.35, SLOT2.35, SLOT3.35, SLOT4.35, SLOT5.35, SLOT6.35, SLOT7.35
unnamed: SLOT0.23, SLOT1.28
unnamed: SLOT0.24, SLOT1.27
unnamed: SLOT1.23, SLOT2.28
unnamed: SLOT1.24, SLOT2.27
unnamed: SLOT2.23, SLOT3.28
unnamed: SLOT2.24, SLOT3.27
unnamed: SLOT4.23, SLOT5.28
unnamed: SLOT4.24, SLOT5.27
unnamed: SLOT5.23, SLOT6.28
unnamed: SLOT5.24, SLOT6.27
unnamed: SLOT6.23, SLOT7.28
unnamed: SLOT6.24, SLOT7.27
PHI0: SLOT0.40, SLOT1.40, SLOT2.40, SLOT3.40, SLOT4.40, SLOT5.40, SLOT6.40, SLOT7.40; also elsewhere on the board
PHI1: SLOT0.38, SLOT1.38, SLOT2.38, SLOT3.38, SLOT4.38, SLOT5.38, SLOT6.38, SLOT7.38; also elsewhere on the board
Q3: SLOT0.37, SLOT1.37, SLOT2.37, SLOT3.37, SLOT4.37, SLOT5.37, SLOT6.37, SLOT7.37; also elsewhere on the board
RDY: SLOT0.21, SLOT1.21, SLOT2.21, SLOT3.21, SLOT4.21, SLOT5.21, SLOT6.21, SLOT7.21; also elsewhere on the board
R~W: SLOT0.18, SLOT1.18, SLOT2.18, SLOT3.18, SLOT4.18, SLOT5.18, SLOT6.18, SLOT7.18; also elsewhere on the board
USER-1: SLOT0.39, SLOT1.39, SLOT2.39, SLOT3.39, SLOT4.39, SLOT5.39, SLOT6.39, SLOT7.39; also elsewhere on the board
~DEV-SEL-0: SLOT0.41; also elsewhere on the board
~DEV-SEL-1: SLOT1.41; also elsewhere on the board
~DEV-SEL-2: SLOT2.41; also elsewhere on the board
~DEV-SEL-3: SLOT3.41; also elsewhere on the board
~DEV-SEL-4: SLOT4.41; also elsewhere on the board
~DEV-SEL-5: SLOT5.41; also elsewhere on the board
~DEV-SEL-6: SLOT6.41; also elsewhere on the board
~DEV-SEL-7: SLOT7.41; also elsewhere on the board
~DMA: SLOT0.22, SLOT1.22, SLOT2.22, SLOT3.22, SLOT4.22, SLOT5.22, SLOT6.22, SLOT7.22; also elsewhere on the board
~INH: SLOT0.32, SLOT1.32, SLOT2.32, SLOT3.32, SLOT4.32, SLOT5.32, SLOT6.32, SLOT7.32; also elsewhere on the board
~IO-SELECT-1: SLOT1.1; also elsewhere on the board
~IO-SELECT-2: SLOT2.1; also elsewhere on the board
~IO-SELECT-3: SLOT3.1; also elsewhere on the board
~IO-SELECT-4: SLOT4.1; also elsewhere on the board
~IO-SELECT-5: SLOT5.1; also elsewhere on the board
~IO-SELECT-6: SLOT6.1; also elsewhere on the board
~IO-SELECT-7: SLOT7.1; also elsewhere on the board
~IO_STB: SLOT0.20, SLOT1.20, SLOT2.20, SLOT3.20, SLOT4.20, SLOT5.20, SLOT6.20, SLOT7.20; also elsewhere on the board
~IRQ: SLOT0.30, SLOT1.30, SLOT2.30, SLOT3.30, SLOT4.30, SLOT5.30, SLOT6.30, SLOT7.30; also elsewhere on the board
~NMI: SLOT0.29, SLOT1.29, SLOT2.29, SLOT3.29, SLOT4.29, SLOT5.29, SLOT6.29, SLOT7.29; also elsewhere on the board
~RESET: SLOT0.31, SLOT1.31, SLOT2.31, SLOT3.31, SLOT4.31, SLOT5.31, SLOT6.31, SLOT7.31; also elsewhere on the board

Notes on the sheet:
DMA OUT => DMA IN
INT OUT => INT IN

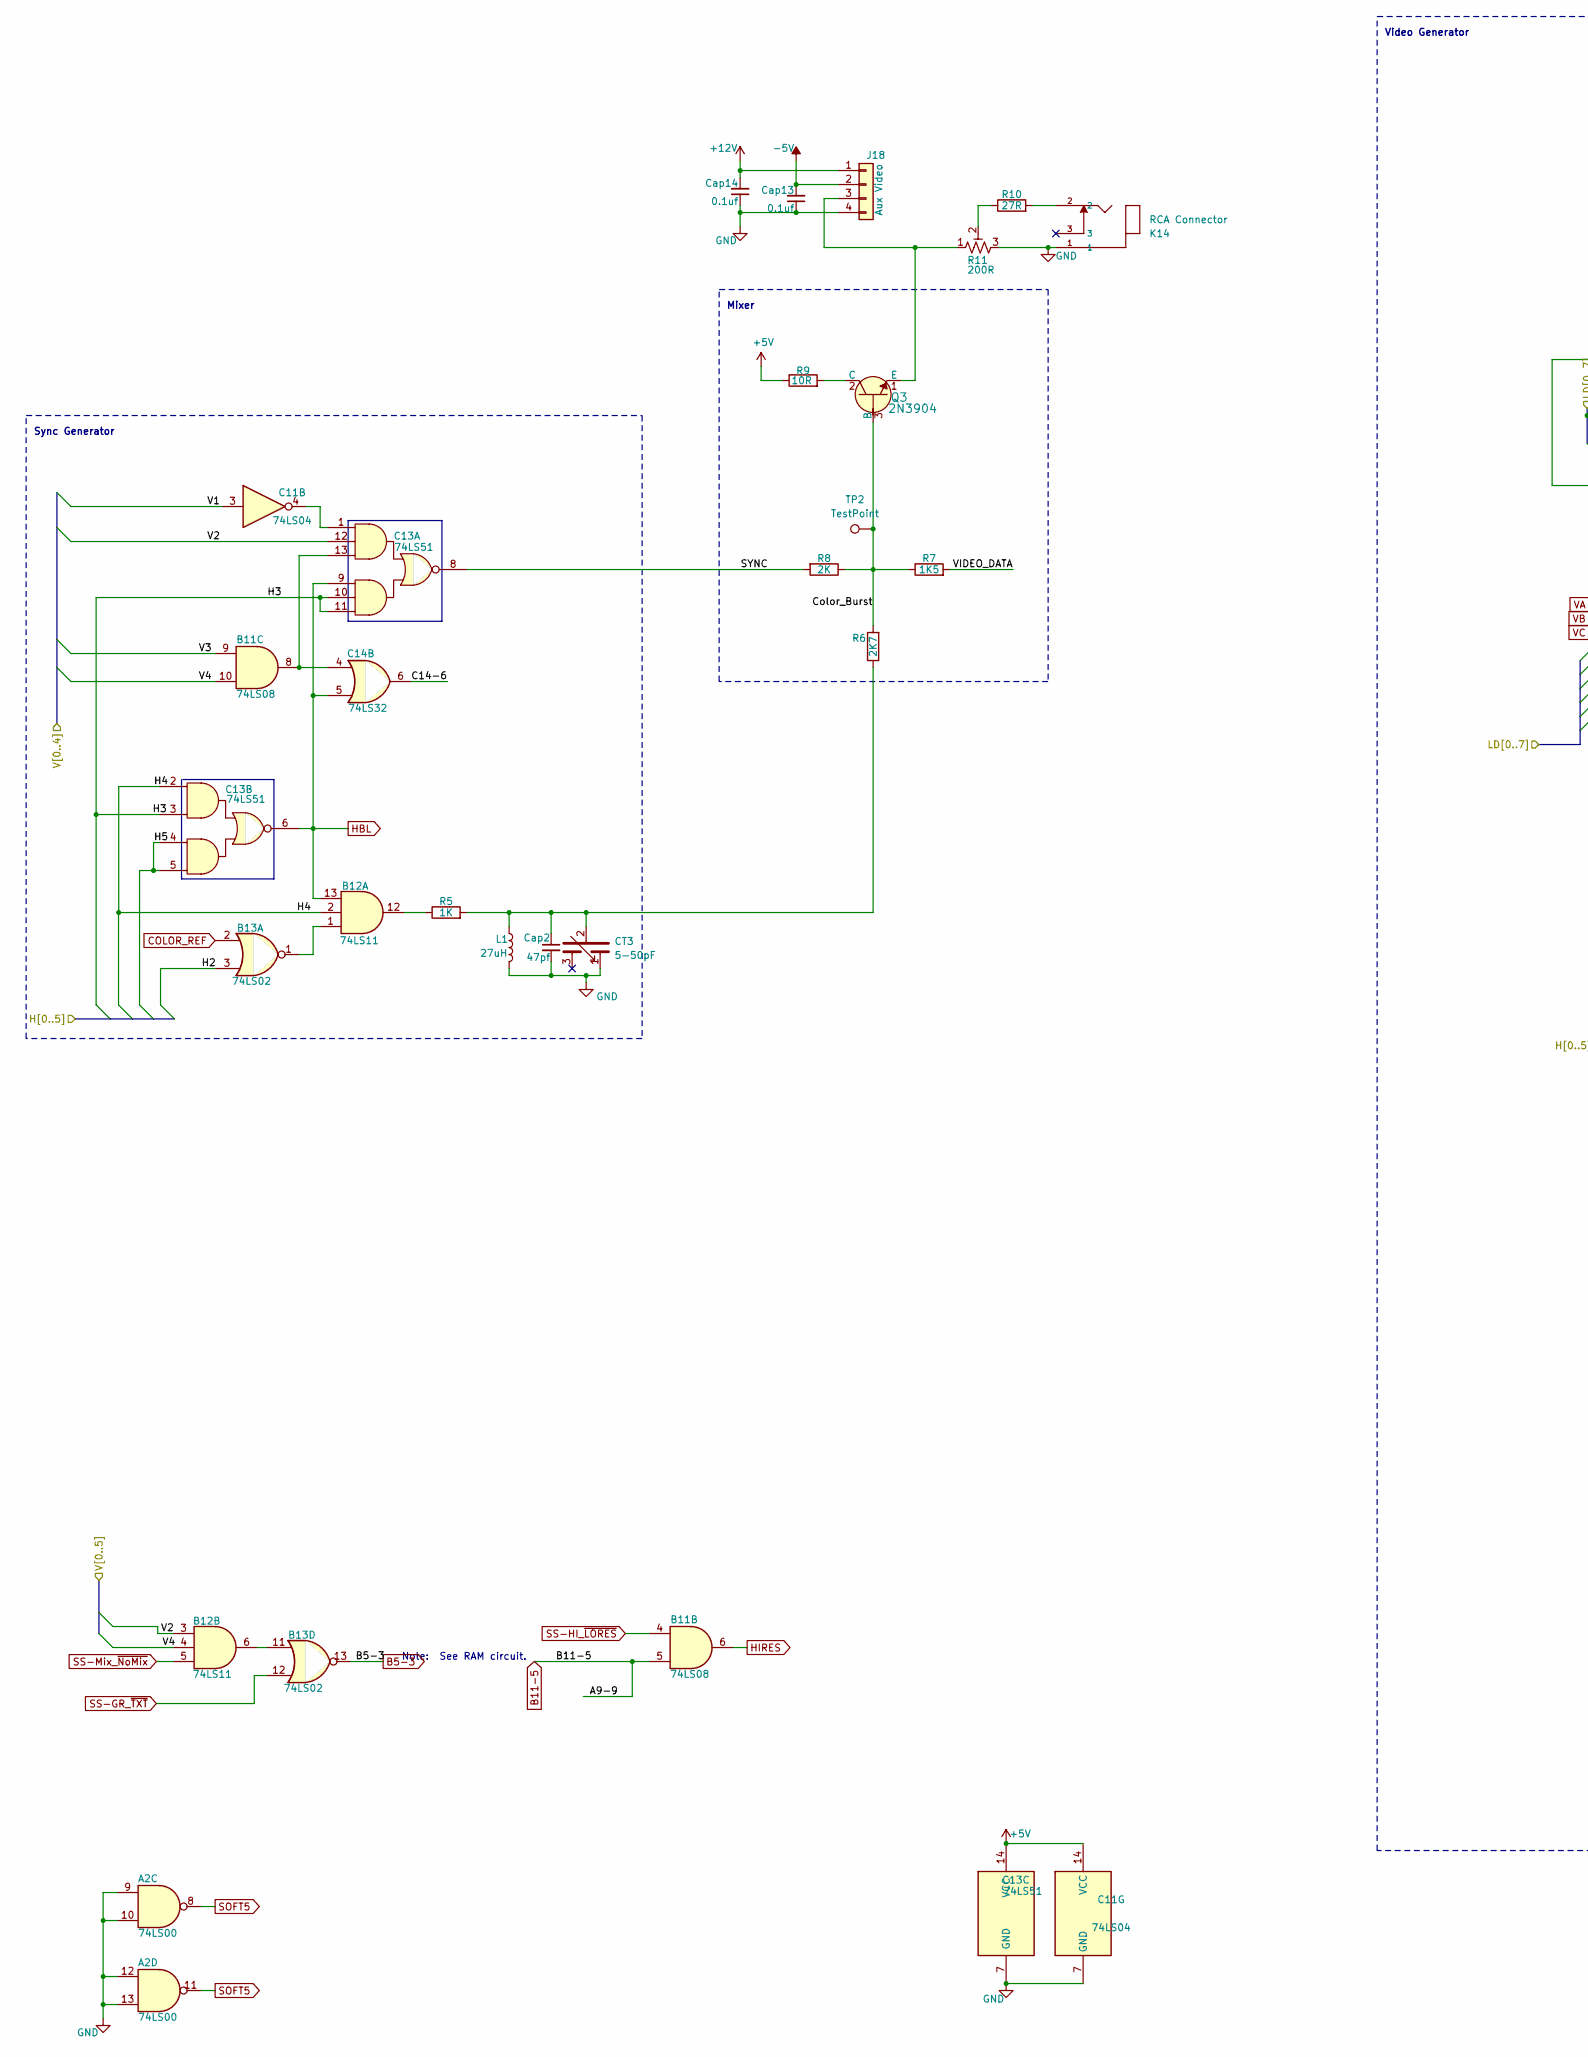
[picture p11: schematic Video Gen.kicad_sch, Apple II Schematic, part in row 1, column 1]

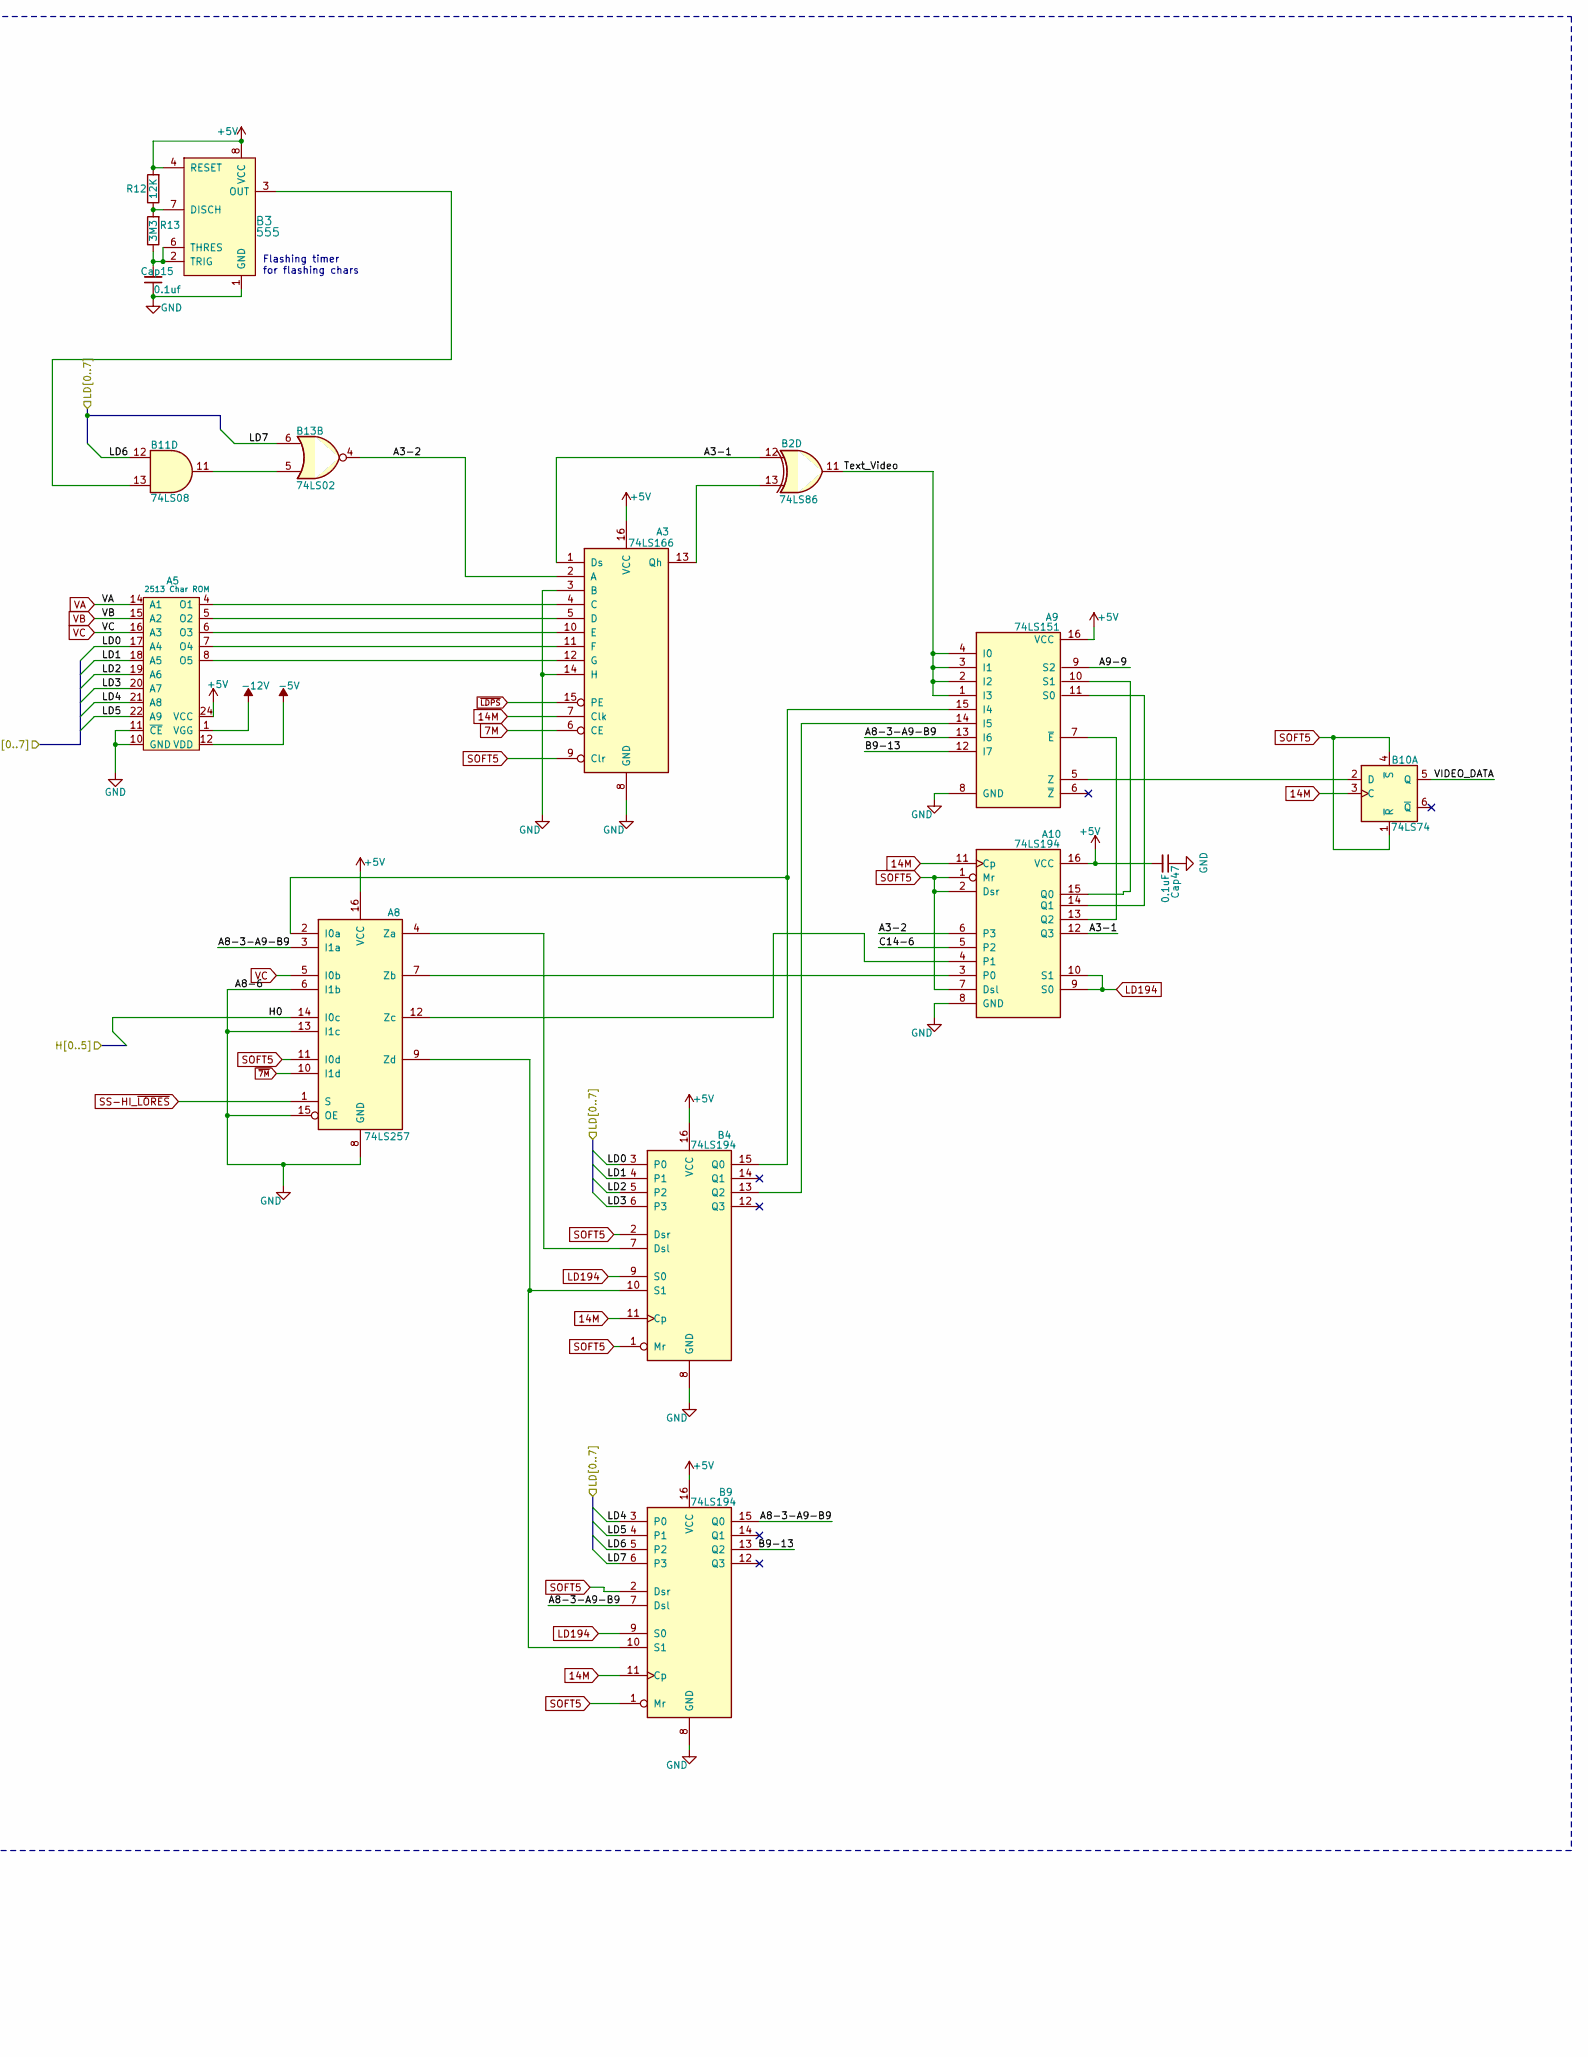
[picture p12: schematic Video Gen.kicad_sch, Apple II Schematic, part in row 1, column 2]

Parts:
A2: 74LS00; DIP-14_W7.62mm
A3: 74LS166; DIP-16_W7.62mm
A5: 2513 Char ROM; DIP-24_W15.24mm
A8: 74LS257; DIP-16_W7.62mm
A9: 74LS151; DIP-16_W7.62mm
A10: 74LS194; DIP-16_W7.62mm
B2: 74LS86; DIP-14_W7.62mm
B3: 555; DIP-8_W7.62mm; MPN NE555P; Digi-Key_PN 296-1411-5-ND
B4, B9: 74LS194; DIP-16_W7.62mm
B10: 74LS74; DIP-14_W7.62mm
B11: 74LS08; DIP-14_W7.62mm
B12: 74LS11; DIP-14_W7.62mm
B13: 74LS02; DIP-14_W7.62mm
C11: 74LS04; DIP-14_W7.62mm
C13: 74LS51; DIP-14_W7.62mm
C14: 74LS32; DIP-14_W7.62mm
CT3: 5-50pF; COLOUR_TRIM; DigiKey BFC280831659-ND
Cap2: 47pf; C_Disc_D7.0mm_W2.5mm_P5.00mm
Cap13, Cap14, Cap15: 0.1uf; C_Disc_D5.0mm_W2.5mm_P5.00mm
Cap47: 0.1uF; C_Disc_D5.0mm_W2.5mm_P5.00mm
J18: Aux Video; PinHeader_1x04_P2.54mm_Vertical
K14: RCA Connector; VIDEO; DigiKey PJRAN1X1U03X-ND
L1: 27uH; L_Axial_L7.0mm_D3.3mm_P12.70mm_Horizontal_Fastron_MICC
Q3: 2N3904; TO-92; MPN 2N3904; Digi-Key_PN 2N3904CS-ND
R5: 1K; R_Axial_DIN0207_L6.3mm_D2.5mm_P10.16mm_Horizontal
R6: 2K7; R_Axial_DIN0207_L6.3mm_D2.5mm_P10.16mm_Horizontal
R7: 1K5; R_Axial_DIN0207_L6.3mm_D2.5mm_P10.16mm_Horizontal
R8: 2K; R_Axial_DIN0207_L6.3mm_D2.5mm_P10.16mm_Horizontal
R9: 10R; R_Axial_DIN0207_L6.3mm_D2.5mm_P10.16mm_Horizontal
R10: 27R; R_Axial_DIN0207_L6.3mm_D2.5mm_P10.16mm_Horizontal
R11: 200R; Potentiometer_Bourns_3266Y_Vertical
R12: 12K; R_Axial_DIN0207_L6.3mm_D2.5mm_P10.16mm_Horizontal
R13: 3M3; R_Axial_DIN0207_L6.3mm_D2.5mm_P10.16mm_Horizontal
TP2: TestPoint

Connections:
7M: A3.6 (CE); also elsewhere on the board
14M: A3.7 (Clk), A10.11 (Cp), B4.11 (Cp), B9.11 (Cp), B10.3 (C); also elsewhere on the board
+5V: A3.16 (VCC), A5.24 (VCC), A8.16 (VCC), A9.16 (VCC), A10.16 (VCC), B3.4 (RESET), B3.8 (VCC), B4.16 (VCC), B9.16 (VCC), C11.14 (VCC), C13.14 (VCC), Cap47.2, R9.1, R12.2; also elsewhere on the board
+12V: Cap14.2, J18.1; also elsewhere on the board
-5V: A5.12 (VDD), Cap13.2, J18.2; also elsewhere on the board
-12V: A5.1 (VGG); also elsewhere on the board
/CPU Tranceiver Driver and Data MUX/LD0: A5.17 (A4), B4.3 (P0); also elsewhere on the board
/CPU Tranceiver Driver and Data MUX/LD1: A5.18 (A5), B4.4 (P1); also elsewhere on the board
/CPU Tranceiver Driver and Data MUX/LD2: A5.19 (A6), B4.5 (P2); also elsewhere on the board
/CPU Tranceiver Driver and Data MUX/LD3: A5.20 (A7), B4.6 (P3); also elsewhere on the board
/CPU Tranceiver Driver and Data MUX/LD4: A5.21 (A8), B9.3 (P0); also elsewhere on the board
/CPU Tranceiver Driver and Data MUX/LD5: A5.22 (A9), B9.4 (P1); also elsewhere on the board
/CPU Tranceiver Driver and Data MUX/LD6: B9.5 (P2), B11.12; also elsewhere on the board
/CPU Tranceiver Driver and Data MUX/LD7: B9.6 (P3), B13.6; also elsewhere on the board
/Clock Generation/H0: A8.14 (I0c); also elsewhere on the board
/Clock Generation/H2: B13.3; also elsewhere on the board
/Clock Generation/H3: C13.3, C13.10, C13.11; also elsewhere on the board
/Clock Generation/H4: B12.2, C13.2; also elsewhere on the board
/Clock Generation/H5: C13.4, C13.5; also elsewhere on the board
/Clock Generation/V1: C11.3; also elsewhere on the board
/Clock Generation/V2: B12.3, C13.12; also elsewhere on the board
/Clock Generation/V3: B11.9; also elsewhere on the board
/Clock Generation/V4: B11.10, B12.4; also elsewhere on the board
/Video Generation/A3-1: A3.1 (Ds), A10.12 (Q3), B2.12
/Video Generation/A3-2: A3.2 (A), A10.6 (P3), B13.4
/Video Generation/A8-3-A9-B9: A8.3 (I1a), A9.13 (I6), B9.7 (Dsl), B9.15 (Q0)
/Video Generation/B9-13: A9.12 (I7), B9.13 (Q2)
/Video Generation/C14-6: A10.5 (P2), C14.6
/Video Generation/Color_Burst: Q3.3 (B), R6.2, R7.1, R8.1, TP2.1
/Video Generation/SYNC: C13.8, R8.2
/Video Generation/Text_Video: A9.1 (I3), A9.2 (I2), A9.3 (I1), A9.4 (I0), B2.11
/Video Generation/VIDEO_DATA: B10.5 (Q), R7.2
B5-3: B13.13; also elsewhere on the board
B11-5: A9.9 (S2), B11.5; also elsewhere on the board
COLOR_REF: B13.2; also elsewhere on the board
GND: A2.9, A2.10, A2.12, A2.13, A3.3 (B), A3.8 (GND), A3.14 (H), A5.10 (GND), A5.11 (~CE), A8.6 (I1b), A8.8 (GND), A8.13 (I1c), A8.15 (OE), A9.8 (GND), A10.8 (GND), B3.1 (GND), B4.8 (GND), B9.8 (GND), C11.7 (GND), C13.7 (GND), CT3.1, Cap2.2, Cap13.1, Cap14.1, Cap15.1, Cap47.1, J18.4, K14.1, L1.2, R11.3; also elsewhere on the board
HBL: B12.13, C13.6, C13.9, C14.5; also elsewhere on the board
HIRES: B11.6; also elsewhere on the board
LD194: A10.9 (S0), A10.10 (S1), B4.9 (S0), B9.9 (S0); also elsewhere on the board
unnamed: A3.4 (C), A5.4 (O1)
unnamed: A3.5 (D), A5.5 (O2)
unnamed: A3.10 (E), A5.6 (O3)
unnamed: A3.11 (F), A5.7 (O4)
unnamed: A3.12 (G), A5.8 (O5)
unnamed: A3.13 (Qh), B2.13
unnamed: A8.2 (I0a), A9.15 (I4), B4.15 (Q0)
unnamed: A8.4 (Za), B4.7 (Dsl)
unnamed: A8.9 (Zd), B4.10 (S1), B9.10 (S1)
unnamed: A9.14 (I5), B4.13 (Q2)
unnamed: A9.5 (Z), B10.2 (D)
unnamed: A8.7 (Zb), A10.3 (P0)
unnamed: A8.12 (Zc), A10.4 (P1)
unnamed: A9.10 (S1), A10.15 (Q0)
unnamed: A9.11 (S0), A10.14 (Q1)
unnamed: A9.7 (~E), A10.13 (Q2)
unnamed: B3.7 (DISCH), R12.1, R13.2
unnamed: B3.3 (OUT), B11.13
unnamed: B3.2 (TRIG), B3.6 (THRES), Cap15.2, R13.1
unnamed: B11.8, C13.13, C14.4
unnamed: B11.11, B13.5
unnamed: B12.1, B13.1
unnamed: B12.6, B13.11
unnamed: B12.12, R5.1
unnamed: C11.4, C13.1
unnamed: CT3.2, Cap2.1, L1.1, R5.2, R6.1
unnamed: J18.3, Q3.1 (E), R11.1
unnamed: K14.2, R10.2
unnamed: Q3.2 (C), R9.2
unnamed: R10.1, R11.2
SOFT5: A2.8, A2.11, A3.9 (Clr), A8.11 (I0d), A10.1 (Mr), A10.2 (Dsr), A10.7 (Dsl), B4.1 (Mr), B4.2 (Dsr), B9.1 (Mr), B9.2 (Dsr), B10.1 (~R), B10.4 (~S); also elsewhere on the board
SS-GR_~TXT: B13.12; also elsewhere on the board
SS-HI_~LORES: A8.1 (S), B11.4; also elsewhere on the board
SS-Mix_~NoMix: B12.5; also elsewhere on the board
VA: A5.14 (A1); also elsewhere on the board
VB: A5.15 (A2); also elsewhere on the board
VC: A5.16 (A3), A8.5 (I0b); also elsewhere on the board
~7M: A8.10 (I1d); also elsewhere on the board
~LDPS: A3.15 (PE); also elsewhere on the board

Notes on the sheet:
Flashing timer for flashing chars
Note: See RAM circuit.
Sync Generator
Mixer
Video Generator

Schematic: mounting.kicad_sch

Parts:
MH1, MH2, MH3, MH4, MH5, MH6, MH7: MountingHole; MountingHole_2.5mm

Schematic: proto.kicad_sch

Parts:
B14: 74LS151; DIP-16_W7.62mm_Socket_LongPads; not fitted
J4, J5: Conn_01x25; SIP-25; not fitted
J6, J7: Conn_01x24; SIP-24; not fitted

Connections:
+5V: B14.16 (VCC); also elsewhere on the board
GND: B14.8 (GND); also elsewhere on the board

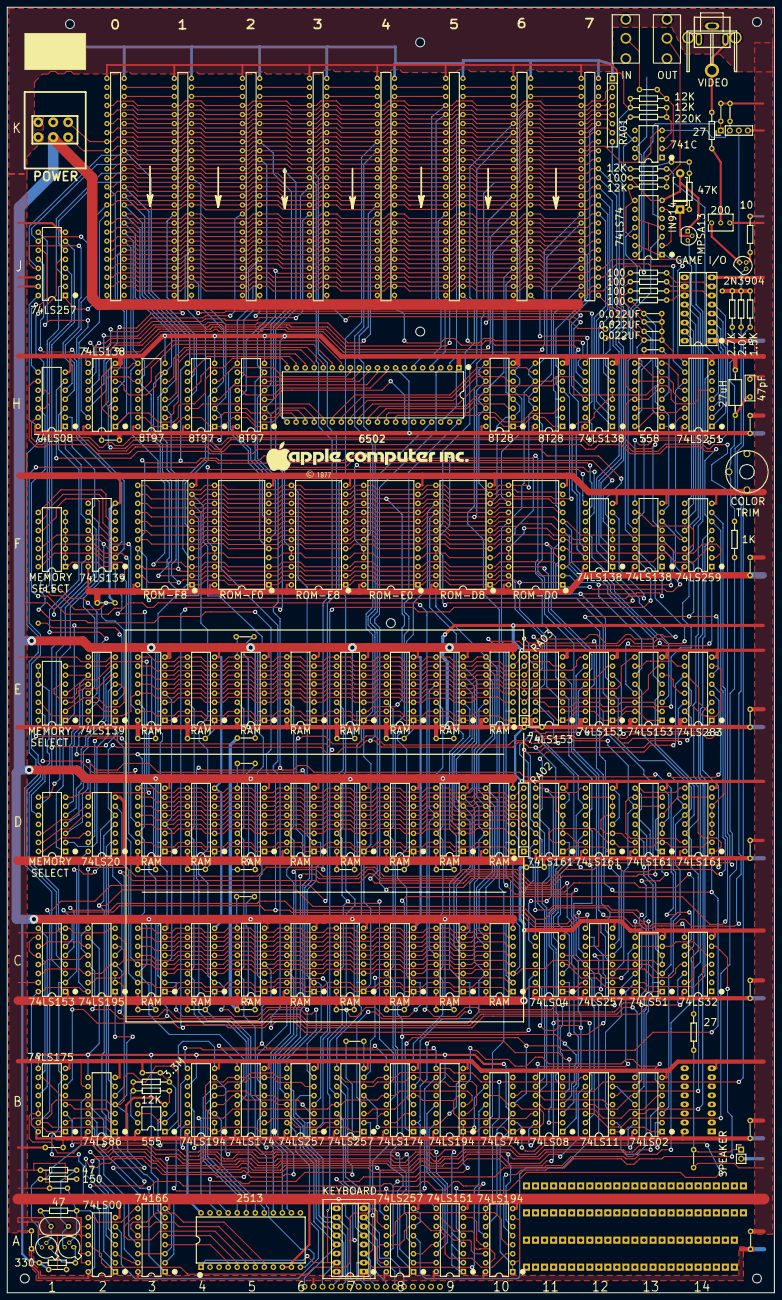
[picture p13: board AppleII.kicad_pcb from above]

Board: 2 copper layers, 215.5 x 361.2 mm, 203 parts (0 on the bottom side), 317 nets.
